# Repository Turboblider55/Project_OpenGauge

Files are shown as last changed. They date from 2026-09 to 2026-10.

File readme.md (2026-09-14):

<div align="center">

# 🛰️ OpenGauge

### Modular Vehicle Telemetry and Infotainment Companion via OBD-II

*A split dual-node wireless dashboard system for real-time vehicle diagnostics.*







[]()

</div>

---

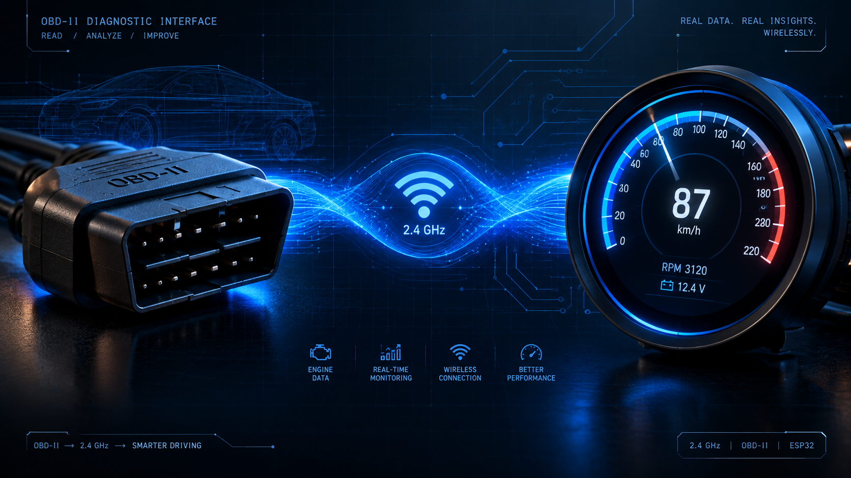
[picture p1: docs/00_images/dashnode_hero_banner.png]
OpenGauge Hero Banner

*<p align="center">OpenGauge — bridging your vehicle's CAN bus to a dashboard-mounted circular telemetry display.</p>*

---

## 📖 Overview

**OpenGauge** is a final-year IT engineering capstone project that decouples vehicle diagnostic acquisition from in-cabin display, connecting the two over a low-latency wireless link. Instead of a single bulky OBD-II dongle with an integrated screen, OpenGauge splits the system into two purpose-built nodes:

- A **discreet acquisition dongle** that lives under the steering column, silently polling the vehicle's CAN bus.
- A **dashboard/vent-mounted display puck** with a crisp circular LCD, delivering smooth animated gauges without any wired connection to the OBD port.

The result is a modular, extensible, and automotive-grade telemetry platform suitable for gauge clusters, data logging, and future infotainment integration.

---

## 🖼️ Visual Reference

| System Architecture | Circular Gauge UI |
|:---:|:---:|
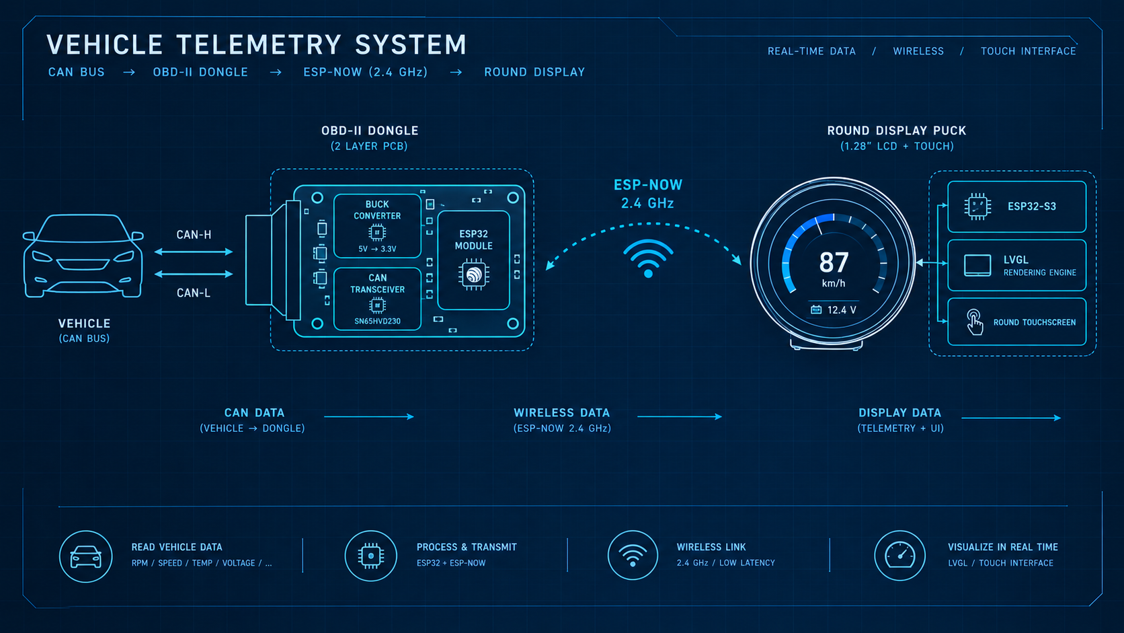
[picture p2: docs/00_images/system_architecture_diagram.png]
System Hardware Architecture Diagram
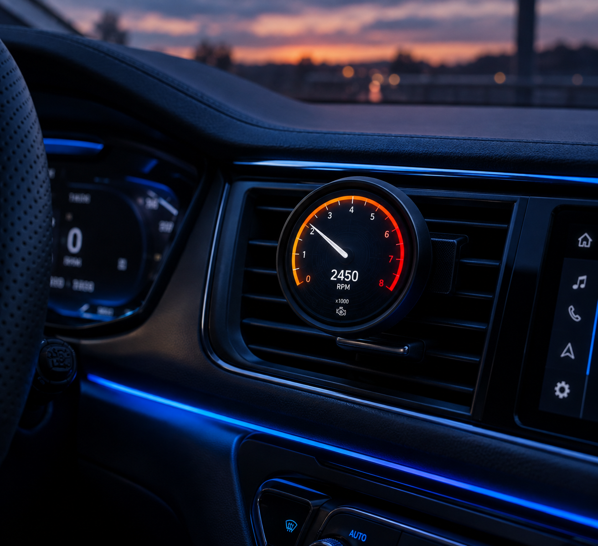
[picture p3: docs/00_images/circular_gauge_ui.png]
Circular Gauge LVGL UI Mockup
|  |  |

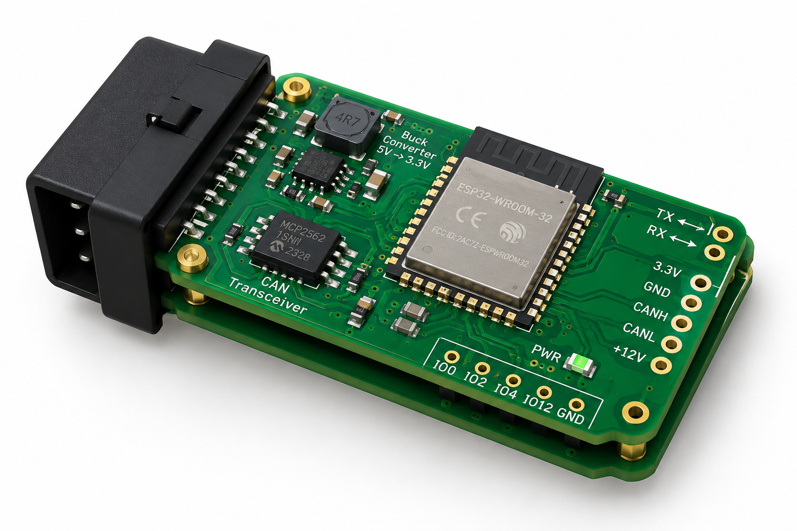
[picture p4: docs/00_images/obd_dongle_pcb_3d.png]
OBD Dongle KiCad 3D PCB Render

*<p align="center">Node 1 — OBD Acquisition Dongle, 2-layer PCB, KiCad 8 3D render.</p>*

---

## ✨ Key Features

### 🔌 Hardware / Electrical
- **Custom 2-layer PCB** for Node 1, sized to fit discreetly behind the J1962 OBD-II port.
- **Automotive-grade buck regulator** (TPS54302 / MP2315) stepping 12V (nominal vehicle rail, 9–16V transient tolerant) down to a clean 3.3V rail.
- **Dedicated CAN physical layer transceiver** (SN65HVD230) interfacing directly with the vehicle's high-speed CAN bus (CAN-H / CAN-L).
- **Input protection stage**: TVS diode transient suppression, reverse-polarity protection diode, and PTC resettable fuse on the 12V input rail.
- **ESP32-C3 module** (castellated-pad, SMD-mountable) as the acquisition MCU — compact footprint, native CAN-capable pin muxing, integrated Wi-Fi/BLE radio for ESP-NOW.
- **USB-C powered Display Node** with an **ESP32-S3** (dual-core Xtensa LX7, 8MB PSRAM) for graphics-heavy LVGL rendering.
- **Waveshare 1.28" Round Touch LCD** — GC9A01 driver (240×240, 4-wire SPI + DMA) with CST816S capacitive touch controller over I2C.

### 📡 Firmware / Protocols
- **ISO 15765-4 (CAN 11-bit, 500 kbps)** OBD-II Mode 01 PID polling: Engine RPM (`0x0C`), Vehicle Speed (`0x0D`), Coolant Temp (`0x05`), Intake Air Temp (`0x0F`).
- **ESP-NOW connectionless peer-to-peer link** — sub-5ms telemetry frame delivery, no router/AP dependency, MAC-address-paired nodes.
- **Custom lightweight binary telemetry packet schema** for minimal air-time and CPU overhead.
- **Watchdog-protected acquisition loop** with automatic PID re-query and CAN bus-off recovery handling.
- **Stretch Goal (Tier 3): BLE AVRCP metadata sniffing** — pairs with a smartphone as an AVRCP-capable BLE peripheral to extract and display the current Spotify track title / artist string on the display node.

### 🎨 Graphics / UI
- **LVGL v8/v9**-driven circular gauge cluster with animated needle sweep, smooth value interpolation, and low-latency screen redraw via DMA-backed SPI transfers.
- **Multi-page swipe UI** (touch-driven) cycling between RPM gauge, speed/temp composite view, and (stretch goal) media metadata card.
- **Configurable gauge redlines and color zones** (e.g., RPM redline warning arc) computed from live telemetry.
- **Boot splash and connection-status iconography** for wireless link health at a glance.

---

## 🧭 System Architecture

```
┌────────────────────────┐
│      VEHICLE ECU       │
│   (CAN-H / CAN-L Bus)  │
└──────────┬─────────────┘
           │  ISO 15765-4 (500 kbps)
           ▼
┌────────────────────────────────────────────┐
│           NODE 1 — OBD ACQUISITION DONGLE  │
│  ┌────────────┐     ┌────────────────┐     │
│  │ J1962 Port │ --> │ SN65HVD230 CAN │     │
│  │  (12V/GND) │     │  Transceiver   │     │
│  └─────┬──────┘     └───────┬────────┘     │
│        │                    │              │
│        ▼                    ▼              │
│  ┌────────────┐     ┌────────────────┐     │
│  │ Buck Reg.  │     │  ESP32-C3      │     │
│  │ 12V→3.3V   │ --> │  (CAN parse +  │     │
│  │(TPS54302)  │     │   PID polling) │     │
│  └────────────┘     └───────┬────────┘     │
└─────────────────────────────┼──────────────┘
                              │
                              │  ESP-NOW (2.4GHz, <5ms)
                              ▼
┌─────────────────────────────────────────────────────┐
│           NODE 2 — DISPLAY NODE                     │
│  ┌───────────────┐     ┌────────────────────┐       │
│  │  ESP32-S3     │ --> │  LVGL v8/v9 Engine │       │
│  │ (Dual-Core,   │     │  (Gauge Rendering) │       │
│  │  8MB PSRAM)   │     └─────────┬──────────┘       │
│  └───────┬───────┘               │                  │
│          │  4-wire SPI + DMA     ▼                  │
│          ▼                 ┌───────────────────┐    │
│  ┌─────────────────┐       │ GC9A01 240x240    │    │
│  │  CST816S Touch  │ <---> │ Round LCD Panel   │    │
│  │  (I2C)          │       └───────────────────┘    │
│  └─────────────────┘                                │
│          USB-C Powered (Dash/Vent Mounted)          │
└─────────────────────────────────────────────────────┘
```

---

## 📁 Repository Structure

```
opengauge/
├── hardware/
│   ├── obd_node_pcb/
│   │   ├── kicad_project/          # .kicad_pro, .kicad_sch, .kicad_pcb
│   │   ├── gerbers/                # Fabrication-ready Gerber + drill files
│   │   ├── bom/                    # Bill of Materials (CSV/XLSX)
│   │   └── 3d_renders/             # STEP/PNG exports
│   └── shared_symbols_footprints/  # Custom KiCad libraries
│
├── firmware/
│   ├── obd_node/                   # ESP32-C3 acquisition firmware
│   │   ├── src/
│   │   │   ├── can_driver.c
│   │   │   ├── obd_pid_parser.c
│   │   │   ├── espnow_tx.c
│   │   │   └── main.c
│   │   ├── include/
│   │   └── platformio.ini
│   │
│   └── display_node/               # ESP32-S3 display firmware
│       ├── src/
│       │   ├── lvgl_conf/
│       │   ├── ui/
│       │   │   ├── gauge_rpm.c
│       │   │   ├── gauge_speed_temp.c
│       │   │   └── media_card.c
│       │   ├── espnow_rx.c
│       │   ├── touch_driver.c
│       │   └── main.c
│       ├── include/
│       └── platformio.ini
│
├── mechanical/
│   ├── dongle_enclosure/           # STL + STEP files, J1962 shroud
│   └── display_puck_mount/         # STL + STEP files, vent/dash clip
│
├── docs/
│   ├── images/                     # README visual assets
│   ├── wiring_diagrams/
│   ├── datasheets/
│   └── project_report.pdf
│
├── LICENSE
└── README.md
```

---

## 🔧 Pin Mapping

### Node 1 — ESP32-C3 (OBD Acquisition Dongle)

| ESP32-C3 Pin | Function | Connected To |
|:---:|:---|:---|
| GPIO4 | `CAN_TX` (TWAI TX) | SN65HVD230 `TXD` |
| GPIO5 | `CAN_RX` (TWAI RX) | SN65HVD230 `RXD` |
| GPIO2 | Status LED — Power | Green LED (via 330Ω resistor)|
| GPIO3 | Status LED — Link | Blue LED (via 330Ω resistor) |
| GPIO8 | Status LED — Fault | Red LED (via 330Ω resistor)  |
| 3V3 | Regulated Supply | TPS54302 `VOUT` |
| GND | Common Ground | Vehicle Chassis / J1962 Pin 4|

### Node 2 — ESP32-S3 (Display Node → Waveshare 1.28" GC9A01/CST816S)

| ESP32-S3 Pin | Function | Display Module Pin |
|:---:|:---|:---|
| GPIO11 | SPI `MOSI` | `SDA` (Display Data) |
| GPIO12 | SPI `SCLK` | `SCL` (Display Clock) |
| GPIO10 | SPI `CS` | `CS` |
| GPIO9 | `DC` (Data/Cmd) | `DC` |
| GPIO14 | `RST` | `RES` |
| GPIO13 | Backlight PWM | `BL` |
| GPIO7 | I2C `SDA` (Touch) | `TP_SDA` (CST816S) |
| GPIO6 | I2C `SCL` (Touch) | `TP_SCL` (CST816S) |
| GPIO15 | Touch `INT` | `TP_INT` |

> ⚠️ Pin assignments are configurable via `sdkconfig` / `platformio.ini` build flags — table reflects default reference firmware wiring.

---

## 🗓️ Development Roadmap (8-Week Capstone Sprint)

| Week | Milestone | Focus Area |
|:----:|:---|:---|
| **1** | Proof-of-Concept | Breadboard ESP32-C3 + MCP2515/SN65HVD230, validate CAN sniffing against a bench ECU simulator or real vehicle OBD port. |
| **2** | OBD Protocol Layer | Implement ISO 15765-4 Mode 01 PID request/response parsing (RPM, Speed, Coolant Temp, Intake Temp). |
| **3** | Wireless Link | Establish ESP-NOW pairing between ESP32-C3 and ESP32-S3; benchmark round-trip latency (<5ms target). |
| **4** | Hardware Fabrication | Finalize KiCad schematic + layout for Node 1 dongle PCB; submit Gerbers for fab; order SMD components. |
| **5** | Display Bring-Up | Bring up Waveshare 1.28" GC9A01 over SPI/DMA; integrate LVGL v8/v9; validate CST816S touch input. |
| **6** | UI/UX Integration | Build animated circular gauge cluster, multi-page swipe navigation, live telemetry binding via ESP-NOW RX. |
| **7** | Enclosure + Stretch Goal | 3D-print/CAD dongle + display puck enclosures; attempt BLE AVRCP Spotify metadata stretch goal. |
| **8** | Final Integration & Defense | End-to-end vehicle testing, documentation finalization, capstone defense presentation & demo. |

---

## 🛠️ Getting Started

### Prerequisites
- [PlatformIO](https://platformio.org/) or ESP-IDF v5.x toolchain
- [KiCad 8](https://www.kicad.org/) for hardware design files
- A vehicle (or CAN bus simulator) with an accessible J1962 OBD-II port
- Basic SMD soldering/rework capability for dongle assembly

### Flashing the Firmware
```bash
# Clone the repository
git clone https://github.com/<your-username>/opengauge.git
cd opengauge

# Flash the OBD Acquisition Node (ESP32-C3)
cd firmware/obd_node
pio run --target upload

# Flash the Display Node (ESP32-S3)
cd ../display_node
pio run --target upload
```

---

## 📜 License & Disclaimer

This project is released under the **MIT License** — see [`LICENSE`](LICENSE) for full terms.

> ⚠️ **Automotive Safety Disclaimer**
> OpenGauge is designed strictly as a **passive, read-only telemetry monitoring device**. It queries standard OBD-II Mode 01 PIDs and does **not** transmit, inject, or alter any CAN bus frames, ECU parameters, or vehicle control systems. This project is intended for educational and diagnostic-display purposes only and is **not** a certified automotive safety, emissions, or control device. Use of this hardware is entirely at the user's own risk; the authors assume no liability for vehicle malfunction, electrical damage, or safety incidents arising from installation or use. Always ensure proper fusing, isolation, and OBD-II port compliance before connecting any custom hardware to a vehicle's diagnostic bus.

---

<div align="center">

**OpenGauge** — Built with ❤️ as a final-year IT Engineering Capstone Project.

</div>

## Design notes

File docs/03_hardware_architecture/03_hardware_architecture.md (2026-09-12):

# 🚗⚡ 03 — Hardware Architecture

> 🔧 **Open Gauge** is a two-board, wireless-linked telemetry system: an **OBD-II Acquisition
> Dongle** 📡 (Board 1, ESP32-C3) that reads the vehicle's CAN bus, and a **Cockpit
> Display Node** 🖥️ (Board 2, ESP32-S3) that renders the data on a round touch
> display. The boards talk to each other over ESP-NOW 📶 — no Wi-Fi router, no
> pairing ceremony, **< 5 ms** typical latency.

📘 This document is a quick-start hardware reference for contributors. For full
derivations, component-selection math, and manufacturing detail, see the
formal hardware specification chapter in `/docs/thesis/`.

---

## 🗺️ 1. High-Level System Architecture

```
                          VEHICLE (12V / 9-16V rail, CAN bus)
 ┌───────────────────────────────────────────────────────────────────────┐
 │  J1962 OBD-II Port                                                    │
 │   Pin16 (12V) Pin4/5 (GND) Pin6 (CAN_H) Pin14 (CAN_L)                 │
 └──────────────┬───────────────────────────┬────────────────────────────┘
                │                            │
                ▼                            ▼
     ┌───────────────────────┐        ┌──────────────────────┐
     │   BOARD 1: OBD        │        │  CAN transceiver     │
     │   ACQUISITION         │◄──────►│  SN65HVD230          │
     │   DONGLE              │        └──────────────────────┘
     │  (ESP32-C3-WROOM-02)  │
     │  - TWAI/CAN polling   │
     │  - Buck 12V→3.3V      │
     │  - Reverse/OV protect │
     └──────────┬────────────┘
                │  ESP-NOW (2.4 GHz, connectionless, ~10 byte packet)
                │  < 5 ms latency, < 3 ms TX time
                ▼
     ┌─────────────────────────┐
     │   BOARD 2: DISPLAY      │
     │   NODE                  │
     │  (ESP32-S3-WROOM-1)     │
     │  - Core0: ESP-NOW/BLE   │
     │  - Core1: LVGL/DMA      │
     │  - GC9A01 round TFT     │
     │  - CST816S touch        │
     │  - USB-C / LiPo power   │
     └───────────┬─────────────┘
                 │
                 ▼
        1.28" round cockpit gauge
        (mounted on vent / bezel)
```

💡 **Design rationale in one line:** splitting acquisition from display lets the
dongle stay small, cheap, and disposable in a harsh electrical environment,
while the display node is optimized purely for graphics and battery-backed
portability — neither board carries silicon it doesn't need.

---

## 🔌 2. Board 1 — OBD-II Acquisition Dongle

### 📐 2.1 Block Diagram

```
 12V IN ──► Reverse-Polarity ──► TVS Clamp ──► TPS54302 ──► 3.3V RAIL
 (Pin16)     (SS34 Schottky)     (SMAJ24A)      Buck Conv.        │
                                                                  ├──► ESP32-C3-WROOM-02
                                                                  └──► SN65HVD230 (CAN PHY)
 CAN_H/L ──► NUP2105L ESD ──► SN65HVD230 ──► GPIO4 (RX) / GPIO5 (TX)
 (Pin6/14)     array            transceiver      of ESP32-C3

 USB-C ──► 5.1k CC pulldowns ──► BAT54 Schottky (back-feed block) ──► GPIO18/19
                                                                       (native USB D-/D+)
```

### 🔋 2.2 Power Step-Down

| ⚙️ Parameter | 📊 Value |
|---|---|
| Topology | Synchronous buck (integrated FET) |
| IC | TI TPS54302 (alt. MPS MP2315) |
| Input range | 4.5 V – 28 V (covers 6 V cold-crank to 40 V load-dump, clamped) |
| Output | 3.3 V @ up to 1.5–2.0 A |
| Switching freq. | 400–500 kHz |
| Inductor | 4.7–10 µH shielded, Isat ≥ 2.0 A |
| Input caps | 10 µF 50 V X7R + 100 nF HF bypass |
| Output caps | 2× 22 µF 10 V X7R |

### 🛰️ 2.3 CAN Bus Transceiver

| ⚙️ Parameter | 📊 Value |
|---|---|
| IC | TI SN65HVD230DR (alt. NXP TJA1051T/3) |
| Standard | ISO 11898-2 (high-speed CAN), used per ISO 15765-4 diagnostic framing |
| Bus speed | 500 kbps, 11-bit ID |
| Termination | 120 Ω footprint on 2-pin jumper JP1, **default OPEN** — vehicle bus already presents the correct ~60 Ω differential load; do not close JP1 in-vehicle |
| ESD protection | NUP2105L (or PESD1CAN) dual-line automotive TVS array on CAN_H/CAN_L |

### 🛡️ 2.4 Safety Isolation

- **Reverse polarity:** SS34 Schottky (40 V, 3 A) in series with the 12 V input pin — blocks reverse-wired power without the drop penalty of a silicon diode bridge.
- **Load dump / OV clamp:** SMAJ24A (or SMBJ28A) unidirectional TVS across 12 V and GND, sized to survive ISO 7637-2 pulse 5 transients.
- **Dual-power conflict:** a BAT54/SS14 Schottky on the USB-C 5 V VBUS rail stops the vehicle-derived 3.3 V/12 V domain from back-feeding a laptop's USB port during bench calibration with the dongle simultaneously plugged into both.

### 🧷 2.5 Board 1 Pinout & Net Map

| ESP32-C3 Pin | Net | Function |
|---|---|---|
| GPIO18 | USB_D- | Native USB Serial/JTAG (flashing) |
| GPIO19 | USB_D+ | Native USB Serial/JTAG (flashing) |
| GPIO04 | CAN_RX | From SN65HVD230 RXD |
| GPIO05 | CAN_TX | To SN65HVD230 TXD |
| GPIO09 | BOOT_SEL | Strapping pin, 10k pullup + tactile switch to GND |
| EN | RESET | 10k pullup + 1 µF to GND |
| GPIO08 | STATUS_LED | Active-low indicator |
| Pin16 (J1962) | VBAT_12V | Vehicle battery feed → reverse-protect → buck |
| Pin6 (J1962) | CAN_H | To transceiver |
| Pin14 (J1962) | CAN_L | To transceiver |
| Pin4/5 (J1962) | GND | Chassis / signal ground |

---

## 🖥️ 3. Board 2 — Cockpit Display Node

### 📐 3.1 Block Diagram

```
 USB-C 5V ──► PTC Fuse ──► SMAJ5.0A ──► TP4056 Charger ──► LiPo Cell (3.7V)
   │            (0805)       clamp           │                   │
   │                                         │                   │
   │  USBLC6-2SC6 ESD array on D+/D-         ▼                   ▼
   │                                  Gate of AO3401A P-FET ◄── 100k pulldown
   ▼                                         │
 ESP32-S3 native USB (GPIO19/20)             ▼
                                   SS14 Schottky ──► SYS_RAIL ──► ME6211C33 LDO ──► 3.3V
                                                                                       │
                                                                            ┌──────────┴──────────┐
                                                                            ▼                      ▼
                                                                   ESP32-S3-WROOM-1        GC9A01 TFT + CST816S
                                                                   (dual-core, 8MB PSRAM)   (SPI + I2C)
```

### 🧠 3.2 Processing Core

- **Module:** ESP32-S3-WROOM-1-N8R8 — dual-core Xtensa LX7 @ 240 MHz, 512 kB SRAM, 8 MB Octal PSRAM, 8 MB Quad SPI flash.
- **Core allocation:** Core 0 runs the ESP-NOW receive/unpack path and background BLE; Core 1 owns the LVGL render loop and DMA-driven SPI transfers to the panel, keeping graphics jitter-free regardless of radio traffic.

### 🎛️ 3.3 Display & Touch Wiring (SPI/I2C)

| Signal | ESP32-S3 GPIO | Bus |
|---|---|---|
| LCD_MOSI | GPIO11 | SPI |
| LCD_SCLK | GPIO12 | SPI |
| LCD_CS | GPIO10 | SPI |
| LCD_DC | GPIO09 | SPI (data/command) |
| LCD_RST | GPIO14 | GPIO |
| LCD_BL | GPIO13 | PWM backlight |
| TOUCH_SDA | GPIO01 | I2C |
| TOUCH_SCL | GPIO02 | I2C |
| TOUCH_INT | GPIO03 | GPIO (interrupt) |
| TOUCH_RST | GPIO04 | GPIO |

Panel: Waveshare 1.28" round IPS TFT, GC9A01 driver, 240×240 RGB565, 4-wire SPI with DMA. Touch: CST816S capacitive controller over I2C.

### 🔌🛡️ 3.4 USB Protection

1. **0805 PTC resettable fuse** — 500 mA hold / 1 A trip, first line of over-current defense.
2. **SMAJ5.0A TVS** — clamps VBUS transients above ~5.5 V.
3. **USBLC6-2SC6** — low-capacitance ESD array on D+/D- to protect the native USB PHY.

### 🔀 3.5 Power-Path Topology (P-MOSFET Auto-Switchover)

The board never runs both sources into the rail simultaneously; instead the
P-channel MOSFET (AO3401A) acts as an ideal-diode-like switch controlled by
VBUS presence:

- 🔌 **USB present:** VBUS pulls the P-FET gate HIGH → FET **off** → system load draws from USB through the SS14 Schottky, while TP4056 charges the LiPo in parallel.
- 🔋 **USB absent:** 100 kΩ pulldown drags the gate to GND → P-FET **on** (< 30 mV drop) → system draws directly from the battery.

Downstream, the ME6211C33M5G LDO (SOT-23-5, 500 mA, ~100 mV dropout) holds a clean 3.3 V rail down to a cell voltage of roughly 3.4 V, covering the LiPo discharge curve down to near-empty.

### 🧷 3.6 Board 2 Pinout & Net Map

| ESP32-S3 Pin | Net | Function |
|---|---|---|
| GPIO19 | USB_D- | Native USB |
| GPIO20 | USB_D+ | Native USB |
| GPIO11 | LCD_MOSI | Display SPI |
| GPIO12 | LCD_SCLK | Display SPI |
| GPIO10 | LCD_CS | Display SPI |
| GPIO09 | LCD_DC | Display SPI |
| GPIO14 | LCD_RST | Display reset |
| GPIO13 | LCD_BL | Backlight PWM |
| GPIO01 | TOUCH_SDA | Touch I2C |
| GPIO02 | TOUCH_SCL | Touch I2C |
| GPIO03 | TOUCH_INT | Touch interrupt |
| GPIO04 | TOUCH_RST | Touch reset |
| GPIO08 | BATT_ADC | Battery sense via 100k/100k divider |

---

## ⚠️ 4. Critical PCB Layout Rules

1. 🔥 **Hot-loop containment (Board 1 buck, Board 2 charger/LDO):** keep the switch node, input cap, and inductor loop as small and tight as physically possible; route the input capacitor's return path directly under the IC's GND pin, not around the board edge. A large hot loop is the single biggest source of radiated EMI on both boards.
2. 🛰️ **Differential CAN routing:** route CAN_H/CAN_L as a tightly coupled differential pair, matched length (±5 mil target), constant spacing, away from the buck converter's switch node and any clock lines. Keep the pair over an unbroken ground reference plane — no plane splits underneath.
3. 📶 **2.4 GHz antenna keepout:** maintain the module vendor's specified copper keepout (typically no copper, silkscreen, or ground pour on any layer directly under or adjacent to the WROOM antenna edge) on both the ESP32-C3 and ESP32-S3 modules, and orient each antenna away from large metal fill and connectors where possible.
4. 🌐 **Star grounding at the power entry:** on Board 1, bring chassis GND and signal GND together at a single point near the J1962 connector rather than merging them arbitrarily across the board, to keep CAN common-mode noise out of the MCU's digital ground.
5. 🔋 **Battery/charge path (Board 2):** keep TP4056 thermal pad and its sense resistor traces short and away from the LDO's heat path; the P-FET body diode orientation must be verified against the schematic before layout — a reversed footprint silently defeats the power-path protection.

---

📎 *For component-level derivations (inductor ripple-current sizing, feedback divider equations, SPI timing/FPS budget, and the full Bill of Materials), see the companion formal hardware specification chapter.*

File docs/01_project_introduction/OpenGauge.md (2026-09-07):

# 🚗 Project Charter & Scope Document: DashNode

**Project Name:** OpenGauge (Modular Vehicle Telemetry and Infotainment Companion via OBD-II)  
**Author:** IT Engineering Candidate  
**Project Type:** Undergraduate Capstone / Final-Year Engineering Project  
**Target Completion:** End of Semester (approx. 6–8 weeks)  
**Status:** 🟡 In Progress  

---

## 📌 1. Executive Summary & Background

Modern passenger vehicles generate substantial telemetry across internal controller area networks (CAN buses), accessible via the mandatory On-Board Diagnostics (OBD-II / J1962) port. However, factory instrument clusters often omit critical real-time performance indicators—such as exact coolant temperatures, oil temperatures, intake manifold pressure, or dynamic bus load. Aftermarket solutions typically fall into two categories: bulky, proprietary gauges that clutter the dashboard with messy power and signal wiring, or generic smartphone apps that require slow manual Bluetooth pairing and drain mobile device batteries.

**OpenGauge** is a modular, split-architecture automotive telemetry platform. It decouples data acquisition from visualization:
* 🔌 An ultra-compact **Dongle Node** plugs directly into the vehicle's OBD-II port, harvesting vehicle power and reading raw high-speed CAN frames.
* 🖥️ A dedicated, dashboard-mounted **Display Node** receives pre-processed telemetry wirelessly, rendering smooth, driver-oriented graphical instruments in real time.

By utilizing dedicated hardware transceivers and a direct peer-to-peer wireless link, DashNode provides a zero-latency, cable-free secondary display that powers on automatically with the vehicle.

---

## 🎯 2. Project Goals & Success Criteria

### 2.1 Primary Engineering Goals
* **[G-1]** 🛠️ Design and fabricate a custom, dual-layer Printed Circuit Board (PCB) integrating an automotive-grade DC-DC buck converter and a dedicated 3.3V CAN physical layer transceiver.
* **[G-2]** ⚡ Implement an embedded firmware pipeline that polls and parses standard ISO 15765-4 (CAN 11-bit/500kbps) OBD-II Parameter IDs (PIDs) with minimal bus latency.
* **[G-3]** 📡 Establish a robust, low-latency, connectionless peer-to-peer wireless telemetry link between the acquisition node and the display node.
* **[G-4]** 📊 Develop a responsive graphical user interface (GUI) on a round/compact TFT display capable of rendering gauge animations at ≥ 30 FPS without blocking communication routines.

### 2.2 Success Metrics
* 🔋 **Power Stability:** On-board buck converter operates reliably with input voltages from $9.0\,\text{V}$ to $16.0\,\text{V}$ DC without thermal throttling or shutdown.
* 🛡️ **Bus Integrity:** Passive read/poll loop introduces zero error frames onto the vehicle's high-speed CAN network.
* ⏱️ **Refresh Rate:** High-priority parameters (Engine RPM, Vehicle Speed) update on screen at $\ge 10\,\text{Hz}$ (latency $\le 100\,\text{ms}$).
* 🚀 **Cold Boot Time:** Display node boots and renders initial telemetry within **a few second** of vehicle ignition switch-on.

---

## 🔍 3. Project Scope & Boundary Definition

### 3.1 In-Scope (Committed Deliverables)
* 📐 **Custom Dongle Hardware:** Schematic capture, component selection, PCB layout, assembly, and testing of the OBD-II acquisition board.
* 🔌 **Power Supply Circuitry:** On-board step-down regulation with reverse-polarity protection, input filtering, and transient voltage suppression (TVS).
* 💻 **Firmware - Acquisition Node:** Initialization of the CAN/TWAI peripheral, cyclic scheduling of standard OBD-II PID requests (Mode 01), message parsing, and wireless packet broadcast.
* 🎨 **Firmware - Display Node:** Wireless packet reception, data validation, and GUI rendering using the LVGL graphics library on a SPI-driven TFT screen.
* 🖨️ **Mechanical CAD:** 3D-printable protective enclosure for the OBD-II dongle conforming to standard J1962 connector envelopes.

### 3.2 Out-of-Scope (Explicitly Excluded)
* ❌ **Writing / Clearing Diagnostic Trouble Codes (DTCs):** To avoid accidental clearing of emissions readiness monitors, the system will operate exclusively as a read-only telemetry display.
* ❌ **Proprietary Manufacturer CAN Reverse-Engineering:** Non-standard manufacturer PIDs (e.g., proprietary BMW, VAG, or Ford factory bus packets) are excluded; the scope is strictly restricted to legislated OBD-II PIDs.
* ❌ **Full-Resolution Video Streaming / Screen Mirroring:** No Android Auto or Apple CarPlay video stream mirroring. The display hardware is optimized for vector UI rendering, not video decoding.
* ❌ **Vehicle Control Intervention:** The system will never transmit actuation frames (accelerator, steering, brake, or body control overrides).

---

## 🚦 4. MVP Constraints & Tiered Feature Breakdown

```
┌───────────────────────────────────────────────────────────┐
│              TIER 1: Minimum Viable Product (MVP)         │
│  • Custom OBD PCB (Buck + CAN + MCU footprint)            │
│  • Vehicle CAN polling: RPM, Speed, Coolant Temperature   │
│  • Peer-to-peer wireless telemetry stream                 │
│  • Basic digital dial & numerical gauge UI on screen      │
└─────────────────────────────┬─────────────────────────────┘
                              │ (If on schedule)
                              ▼
┌───────────────────────────────────────────────────────────┐
│                 TIER 2: Core Engineering Polish           │
│  • Low-power sleep mode during engine-off state           │
│  • Secondary screens: Min/Max trip telemetry, Intake Temp │
│  • 3D-printed clip/case for air-vent mounting             │
└─────────────────────────────┬─────────────────────────────┘
                              │ (Strictly optional)
                              ▼
┌───────────────────────────────────────────────────────────┐
│                 TIER 3: Extended / Stretch Goals          │
│  • Bluetooth AVRCP (Spotify Track / Artist text display)  │
│  • Turn-by-Turn navigation arrow icon notification parsed │
│    from companion mobile app / BLE notification service   │
└───────────────────────────────────────────────────────────┘
```

### Critical MVP Technical Constraints
* ⚡ **Safety Isolation:** Solder jumper must allow disabling the $120\,\Omega$ bus termination resistor to prevent over-terminating an active vehicle CAN bus.
* 📏 **Board Dimensions:** OBD dongle PCB footprint must not exceed $55\,\text{mm} \times 35\,\text{mm}$ to prevent interference with driver footwell controls.
* 📦 **Component Availability:** All silicon (switching ICs, transceivers, passives) must be selected from in-stock parts at standard rapid-assembly vendors (e.g., JLCPCB SMT library / LCSC).

---

## 📦 5. Project Deliverables

| Deliverable ID | Category | Description | Format / Artifact |
| :--- | :--- | :--- | :--- |
| **DEL-01** | 📄 Documentation | Complete System Architecture & Functional Specification | Markdown / PDF in `/docs` |
| **DEL-02** | 🖥️ Hardware | KiCad Schematic, PCB Layout, Gerber & Drill files | `.kicad_sch`, `.kicad_pcb`, zip in `/hardware` |
| **DEL-03** | 📋 Hardware | Bill of Materials (BOM) with vendor LCSC/DigiKey part numbers | `bom.csv` |
| **DEL-04** | 💻 Firmware | Acquisition Node firmware (CAN parsing + Wireless TX) | C++ source code in `/firmware/obd_node` |
| **DEL-05** | 🎨 Firmware | Display Node firmware (LVGL UI + Wireless RX) | C++ source code in `/firmware/display_node` |
| **DEL-06** | 🖨️ Mechanical | Enclosure CAD models for 3D printing | `.step` / `.stl` in `/mechanical` |
| **DEL-07** | 🎓 Academic | Final Thesis Paper & Demonstration Video | Final University Report (PDF) |

---

## ⚠️ 6. Risk Management & Contingency Matrix

| Identified Risk | Severity | Likelihood | Mitigation Strategy |
| :--- | :--- | :--- | :--- |
| **PCB Layout/Fab Error** (e.g., buck converter failure) | 🔴 High | 🟡 Medium | Order bare breakouts of key ICs in parallel; reserve space for manual bodge-wires; follow reference layouts strictly. |
| **Vehicle Incompatibility** (ECU timeout or silent bus) | 🔴 High | 🟢 Low | Develop on a bench setup using an inexpensive USB-to-CAN analyzer or a secondary MCU programmed as an OBD-II simulator. |
| **Display Framerate Lag** (SPI bus blocking execution) | 🟡 Medium | 🟡 Medium | Use ESP32 dual-core task affinity: Core 0 dedicated to wireless communication, Core 1 running LVGL graphics with DMA-driven SPI. |
| **Bluetooth Phone Stack Complexity** (Timeline threat) | 🟡 Medium | 🔴 High | Lock BLE/Spotify/Maps features strictly to Tier 3. If MVP is running behind schedule by Week 5, drop BLE phone integration entirely without risking project pass criteria. |

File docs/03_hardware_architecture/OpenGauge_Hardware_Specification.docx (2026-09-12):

Hardware Engineering Chapter

Open Gauge: An Open-Source, Dual-Node Wireless Vehicle Telemetry and Secondary Instrument Gauge Platform

This chapter presents the complete hardware engineering specification for Open Gauge, covering system-level design rationale, the OBD-II acquisition dongle (Board 1), the cockpit display node (Board 2), the consolidated bill of materials, and the manufacturing and PCB layout guidelines used to realize the design.

# 1. System-Level Design Rationale

## 1.1 Asymmetric Dual-Node Topology

Open Gauge partitions functionality across two physically separate, wirelessly linked printed circuit boards rather than adopting the conventional single-board approach used by most hobbyist OBD-II gauge projects. Board 1 (the Acquisition Dongle) resides permanently inside the OBD-II tunnel, exposed to the harshest electrical environment in the vehicle, while Board 2 (the Display Node) is a battery-backed, purely-digital cockpit instrument mounted for driver visibility. This asymmetry is a deliberate engineering decision, not an artifact of convenience, and is justified along four axes below.

### 1.1.1 Electrical isolation of the hostile domain

A traditional single-board wired gauge cluster must route both the raw vehicle power/CAN domain and the low-noise display/touch domain on one substrate, forcing the sensitive SPI and I2C traces feeding the display controller to share a ground plane with a switching buck converter fed directly from an unregulated automotive rail. By splitting the boards, all automotive-grade transient handling (load dump, reverse polarity, ESD on the CAN lines) is physically confined to Board 1, and the only signal crossing the boundary to Board 2 is a 2.4 GHz radio packet — there is no galvanic connection between the vehicle electrical system and the cockpit-mounted display at all.

### 1.1.2 Independent power budgets and duty cycles

Board 1 is permanently powered whenever the vehicle battery is connected (or gated by switched 12 V, depending on installation), and its power budget is dominated by the CAN transceiver and RF broadcast duty cycle. Board 2 is a battery-powered, user-facing instrument that must survive extended operation off a small LiPo cell when removed from USB power, and its budget is dominated by the TFT backlight and the LVGL render pipeline. Decoupling the two boards allows each power subsystem to be optimized independently: Board 1 needs a wide-input automotive buck regulator, while Board 2 needs an efficient linear power-path with instant source switchover rather than a second automotive-rated buck stage it would never use in normal operation.

### 1.1.3 Mechanical placement freedom

The OBD-II port is fixed by the vehicle manufacturer under the steering column, an ergonomically poor location for a driver-facing gauge. A single-board design would force an unsightly cable run from the port to the dash. The dual-node topology lets Board 1 remain hidden at the port while Board 2 is placed anywhere convenient — vent-mounted, bezel-mounted, or handheld — with ESP-NOW eliminating the wiring harness entirely.

### 1.1.4 Fault containment and field serviceability

Because the boards are only coupled over RF, a fault on one node (e.g. a CAN transceiver damaged by an out-of-spec transient) cannot propagate to or brick the other. Each board can be reflashed, replaced, or bench-tested independently over its native USB interface without disturbing the other node, which materially reduces field-service complexity relative to a monolithic board where a single fault domain covers both acquisition and display electronics.

## 1.2 Automotive Power Rail Dynamics

Board 1 draws power directly from the vehicle’s 12 V nominal rail at the OBD-II connector, a supply that is nominal in name only. The regulator, input protection network, and PCB layout were all sized against the transient environment defined by ISO 7637-2 and observed alternator/starter behavior, summarized below.

Transient class | Origin | Typical magnitude
Pulse 1 | Supply line disconnect while inductive loads are switched | −100 V (clamped), fast decay
Pulse 2a | Supply interruption due to voltage drop at wiring resistance | +75 V transient, short duration
Pulse 3a/3b | Transients from switching processes on the bus wiring | ±150 V, sub-microsecond, fast repetitive
Pulse 5b (load dump) | Alternator field-decay after battery disconnect under charge | +40 V typical, several hundred ms, up to seconds
Cold crank | Starter motor draw collapsing battery voltage | Down to 6 V for ~15–20 ms, ringing recovery
Alternator ripple | Rectifier ripple superimposed on the charging rail | ±0.5–1 V at 3× to 6× engine RPM harmonic

Table 1.1 — ISO 7637-2 conducted transient classes relevant to the Board 1 input stage.

The design response to this environment is layered rather than relying on a single component: the TPS54302 buck regulator is specified for a 4.5–28 V continuous input range, comfortably spanning cold-crank sag (6 V) through nominal charging voltage (13.8–14.4 V); a SMAJ24A/SMBJ28A unidirectional TVS diode clamps load-dump energy at the input before it reaches the regulator’s absolute maximum rating; and the SS34 series Schottky diode blocks reverse-polarity connection at the connector, which — unlike the transient pulses above — is a static fault condition rather than a momentary event and must be tolerated indefinitely without damage. Alternator ripple, being a relatively low-amplitude, low-frequency artifact well within the buck converter’s input operating range and further attenuated by the input bulk capacitance, does not require dedicated suppression beyond the standard input filter network.

# 2. Board 1: OBD-II Telemetry Acquisition Dongle

## 2.1 Core Processing: ESP32-C3-WROOM-02

Board 1 is built around the Espressif ESP32-C3-WROOM-02-N4 castellated SMT module, integrating a 32-bit single-core RISC-V processor, 4 MB of SPI flash inside an RF shielding can, and the on-chip TWAI (Two-Wire Automotive Interface) controller that implements the CAN 2.0B protocol engine used for OBD-II polling.

The core clock is derived from a 40 MHz external crystal reference through the chip’s internal phase-locked loop, which multiplies the reference up to the processor’s 160 MHz operating frequency:

fCPU = fXTAL × NPLL = 40 MHz × 4 = 160 MHz

This single-core budget is sufficient because Board 1’s workload is I/O-bound rather than compute-bound: the dominant task is scheduling periodic CAN request frames, parsing single-frame ISO 15765-4 responses, and packing the result into a fixed 10-byte ESP-NOW payload, none of which approaches the processor’s throughput ceiling even at the fast-polling group’s 10–20 Hz cadence.

## 2.2 Power Stage Analysis — TPS54302 Synchronous Buck

The TPS54302 is a synchronous step-down converter with integrated high-side and low-side FETs, selected for its wide 4.5–28 V input range (matching the transient envelope described in §1.2), integrated compensation, and small external component count. The design targets a fixed 3.3 V output at up to 1.5–2.0 A, switching at approximately 400–500 kHz.

### 2.2.1 Output inductor selection

The output inductor is sized from the target peak-to-peak ripple current, expressed as a fraction KIND of the maximum DC load current (a design value of KIND = 0.3 – 0.4 is standard practice for this class of automotive buck converter, balancing inductor size against ripple-induced core and conduction losses):

L1 = [VOUT × (VIN(max) − VOUT)] / [VIN(max) × fSW × ΔIL]

where ΔIL = KIND × IOUT(max). Substituting a worst-case VIN(max) of 16 V (clamped alternator ceiling), VOUT = 3.3 V, fSW = 450 kHz, IOUT(max) = 1.5 A and KIND = 0.35 gives ΔIL ≈ 0.525 A and yields an inductor value in the 6.5–7.5 µH range — consistent with the specified 4.7–10 µH shielded power inductor with a saturation current rating ISAT ≥ 2.0 A, which retains adequate margin above the calculated peak current (IOUT(max) + ΔIL/2 ≈ 1.76 A).

### 2.2.2 Input capacitor ESR and RMS current

The buck converter draws pulsed current from the input rail at the switching frequency; the input capacitor must supply this ripple current locally so that only DC (and low-frequency alternator ripple, already discussed) is drawn from the harness. The input capacitor RMS current requirement is approximated by:

ICIN(RMS) ≈ IOUT × √[D × (1 − D)]

where D = VOUT/VIN is the converter duty cycle. At the nominal 13.8 V input, D ≈ 0.24, giving ICIN(RMS) ≈ 0.65 × IOUT. The specified 10 µF 50 V X7R ceramic input capacitor, combined with a 100 nF high-frequency bypass placed immediately at the IC’s VIN pin, presents ESR in the low tens of milliohms — low enough that the resulting input ripple voltage (ΔVIN ≈ ICIN(RMS) × ESR) stays a small fraction of a volt, well within the regulator’s tolerance for line noise.

### 2.2.3 Feedback divider for fixed 3.3 V output

For adjustable-output variants of this converter family, the output voltage is programmed by a resistive divider from VOUT to the feedback pin, referenced against the internal bandgap VREF (typically 0.8 V):

VOUT = VREF × (1 + R1/R2)

Rearranged for a fixed 3.3 V target with a standard R2 = 10.0 kΩ (1% tolerance) lower divider resistor:

R1 = R2 × (VOUT/VREF − 1) = 10.0 kΩ × (3.3/0.8 − 1) ≈ 31.25 kΩ

The nearest E96 1% value (31.6 kΩ) is used in practice, giving an actual output of approximately 3.328 V — within the ±2% tolerance the downstream digital logic and CAN transceiver both accept.

## 2.3 Physical CAN Bus Interface — SN65HVD230

The SN65HVD230DR is a 3.3 V-native CAN transceiver compliant with ISO 11898-2, chosen specifically because it eliminates the level-shifting network that would otherwise be required between a 3.3 V MCU and a 5 V-logic transceiver, reducing both component count and an additional failure surface on the bus-facing side of the board.

TVS protection is provided by a NUP2105L dual-line automotive ESD/EFT suppressor placed directly across CAN_H and CAN_L, as close to the J1962 connector as routing allows, so that transient energy is diverted before it reaches the transceiver’s bus pins.

The 120 Ω termination footprint (JP1) is deliberately left open by default. Vehicle CAN buses already present the correct differential termination (typically two 120 Ω terminators at the ECU and gateway ends of the bus, combining to a nominal 60 Ω differential load); adding a third 120 Ω termination at the dongle would over-load the bus, degrading signal integrity rather than improving it. JP1 exists only to permit standalone bench testing of Board 1 against a CAN bus simulator, where no other termination is present.

## 2.4 Dual-Power Conflict Prevention

During bench calibration it is common to have Board 1 connected simultaneously to a laptop (via USB-C, for flashing/logging) and to a bench 12 V supply or live vehicle harness (for CAN traffic). Without protection, the buck converter’s 3.3 V output — or in a fault condition, the raw 12 V rail — could back-feed through the USB connector into the laptop’s USB port. A low forward-voltage Schottky diode (BAT54 or SS14) is placed in series with the USB-C 5 V VBUS net, oriented so that current can only flow from the USB host into the board, never the reverse direction, isolating the two supply domains during concurrent connection.

# 3. Board 2: Cockpit Instrument Display Node

## 3.1 Processing Core — ESP32-S3-WROOM-1-N8R8

Board 2 uses the dual-core Xtensa LX7 ESP32-S3-WROOM-1-N8R8 module, clocked at 240 MHz from the same 40 MHz-reference PLL architecture used on Board 1, with 512 kB internal SRAM augmented by 8 MB of embedded Octal PSRAM and 8 MB of Quad SPI flash. The additional core (relative to Board 1’s single-core part) and the PSRAM frame buffer are both required by the graphics workload rather than by the wireless link.

Task allocation is fixed by design: Core 0 owns the wireless protocol stack — unpacking incoming ESP-NOW telemetry frames and servicing background BLE tasks — while Core 1 is dedicated exclusively to the LVGL rendering pipeline and the DMA-driven SPI transfer to the display controller. This separation ensures that radio interrupt servicing never stalls the frame render loop, and that a full 240×240 RGB565 frame buffer (240 × 240 × 2 bytes = 115,200 bytes per frame) can be held in PSRAM without contending with the 512 kB internal SRAM budget needed for the wireless stack and LVGL object heap.

## 3.2 Display & Touch Subsystem

The panel is a Waveshare 1.28-inch circular IPS TFT (240×240, RGB565, active diameter ≈ 32.4 mm) driven by the GC9A01 controller over a 4-wire SPI interface (MOSI, SCLK, CS, DC) with DMA-assisted transfers, paired with a CST816S capacitive touch controller on a standard I2C bus.

### 3.2.1 SPI throughput and frame-rate budget

Each full-frame transfer moves the entire 115,200-byte RGB565 buffer across the SPI bus. At a 40 MHz SPI clock, the raw bit rate available for data transfer is:

Rbit = fSPI = 40 × 10⁶ bit/s ⇒ Rbyte = 5 × 10⁶ byte/s (ideal, 8 bit/clk)

The minimum time to shift out one full frame is therefore:

tframe = Bytesframe / Rbyte = 115,200 / 5,000,000 ≈ 23.0 ms

which corresponds to a theoretical ceiling of roughly 43 FPS for full-frame refresh. In practice LVGL is configured to redraw only the dirty rectangles that changed between frames (needle sweep, changing digits) rather than the full 240×240 buffer every cycle; for a typical dirty-region update covering roughly half the panel area, the transfer time roughly halves to ≈ 11.5 ms, and combined with the DMA engine offloading the transfer from the CPU (allowing LVGL to begin composing the next frame while the previous DMA transfer is still in flight), the pipeline comfortably sustains greater than 30 FPS, satisfying the design requirement.

## 3.3 USB Input Protection

The USB-C input on Board 2 is protected by a three-stage network: an 0805 surface-mount PTC resettable fuse (500 mA hold / 1 A trip) provides recoverable over-current protection ahead of the charger and system load; a SMAJ5.0A unidirectional TVS diode clamps VBUS transients above approximately 5.5 V; and a USBLC6-2SC6 low-capacitance ESD array protects the D+/D- native-USB data lines without introducing enough parasitic capacitance to distort full-speed USB signal integrity.

## 3.4 Dynamic Hardware Power-Path & Battery Subsystem

Board 2 must transition seamlessly between USB power and a single-cell 3.7 V LiPo battery (500–1000 mAh) without a software-mediated switchover, since a firmware fault or reset must never leave the display node unpowered mid-transition. This is achieved with a purely analog power-path built from a TP4056 (or MCP73831) linear charger, an AO3401A P-channel MOSFET, and a small Schottky diode network.

### 3.4.1 Switching dynamics — USB plug-in event

- VBUS rises to 5 V; the TP4056 detects input power and begins charging the LiPo cell (current limited by RPROG, configured for ≈ 400 mA).
- The same VBUS rail is applied to the gate of the AO3401A P-channel MOSFET through the gate network; because VGS becomes strongly positive relative to the battery-referenced source, the P-FET turns OFF, disconnecting the battery from the system rail.
- System load current is now supplied from VBUS through the SS14/BAT54C Schottky diode directly to the system rail, in parallel with (but electrically isolated from) the charging path into the battery.

### 3.4.2 Switching dynamics — USB unplug event

- VBUS collapses toward 0 V; the TP4056 charge path ceases sourcing current.
- The 100 kΩ pulldown resistor on the P-FET gate, no longer overridden by VBUS, pulls the gate toward the battery-referenced source potential.
- As VGS crosses the AO3401A’s threshold, the P-FET turns ON, presenting an ultra-low on-resistance path (< 30 mV drop at typical system load) directly from the battery to the system rail.
- The transition is continuous and sub-millisecond: because the P-FET body diode is oriented to conduct from battery to system rail even before the channel fully turns on, there is no interruption of supply to the ME6211C33 LDO input during the handover, and no visible flicker or reset on the display.

## 3.5 LDO Regulation — ME6211C33

The ME6211C33M5G (SOT-23-5) provides the final regulated 3.3 V system rail from either the USB-derived or battery-derived unregulated input, with a rated output current of 500 mA and a low dropout voltage of approximately 100 mV at 200 mA load. Because the LiPo discharge curve sags toward roughly 3.4 V near end-of-discharge, the LDO’s dropout margin — 3.4 V input minus 3.3 V output leaves only 100 mV of headroom at the low end of the curve — is the limiting factor that defines the battery’s usable depth of discharge before the display node begins to brown out; this is consistent with, and was a driving constraint on, the LDO part selection.

# 4. Complete Bill of Materials

The following tables consolidate every functional component referenced in §2 and §3. Passive component tolerances are 1% for feedback/sense resistors and 10% (X7R or better) for ceramic capacitors unless otherwise noted.

## 4.1 Board 1 — OBD-II Acquisition Dongle BOM

Ref | Value / Part | Package | Recommended P/N | Function
U1 | ESP32-C3-WROOM-02-N4 | SMD Module | Espressif ESP32-C3-WROOM-02-N4 | MCU / RISC-V / CAN(TWAI) / RF
U2 | TPS54302DDCR | SOT-23-6 (Thin) | TI TPS54302DDCR | 3.3V synchronous buck regulator
U3 | SN65HVD230DR | SOIC-8 | TI SN65HVD230DR | CAN 2.0B / ISO 11898-2 transceiver
D1 | SS34 | SMA / DO-214AC | Diodes Inc. SS34 | Reverse-polarity protection
D2 | SMAJ24A | SMA / DO-214AC | Littelfuse SMAJ24A | Load-dump / OV TVS clamp
D3 | NUP2105L | SOT-23 | onsemi NUP2105L | CAN_H/CAN_L ESD/EFT suppressor
D4 | BAT54 / SS14 | SOT-23 / SMA | Diodes Inc. BAT54 | USB back-feed block diode
L1 | 6.8 uH shielded inductor | 4x4 mm SMD shielded | TDK / Wurth SD-series, Isat>=2.0A | Buck output inductor
C1 | 10 uF 50V X7R | 1210 | Murata GRM32 series | Buck input bulk capacitor
C2 | 100 nF 50V X7R | 0603 | Generic MLCC | Buck input HF bypass
C3,C4 | 22 uF 10V X7R | 0805 | Murata GRM21 series | Buck output filter (x2)
R1 | 31.6 k ohm 1% | 0402 | Generic thin-film | FB divider upper (V_OUT set)
R2 | 10.0 k ohm 1% | 0402 | Generic thin-film | FB divider lower (V_OUT set)
R3 | 10 k ohm | 0402 | Generic | EN pullup
R4 | 10 k ohm | 0402 | Generic | BOOT_SEL (GPIO09) pullup
R5 | 5.1 k ohm | 0402 | Generic (x2, CC1/CC2) | USB-C CC pulldowns
JP1 | 2-pin solder jumper | SMD pad pair | Generic | 120 ohm CAN termination (default open)
R_TERM | 120 ohm 1% | 0603 | Generic | CAN termination resistor (footprint only)
J1 | J1962 OBD-II connector | Through-hole / cable mount | TE / generic OBD-II shell | Vehicle bus interface
J2 | USB-C receptacle | SMD, 16-pin | GCT / Amphenol USB4085/4110 | Flashing / bench power
SW1 | Tactile switch | SMD 6mm | Generic | Manual bootloader entry
LED1 | Status LED (red/green) | 0603 | Generic | Active-low status indicator

## 4.2 Board 2 — Cockpit Display Node BOM

Ref | Value / Part | Package | Recommended P/N | Function
U1 | ESP32-S3-WROOM-1-N8R8 | SMD Module | Espressif ESP32-S3-WROOM-1-N8R8 | Dual-core MCU / PSRAM / RF
U2 | GC9A01 display module | FPC + round glass | Waveshare 1.28" round LCD | 240x240 SPI TFT controller/panel
U3 | CST816S | COF on FPC (module) | Hynitron CST816S | Capacitive touch controller
U4 | TP4056 | SOP-8 (ESOP8) | Nanjing Top Power TP4056 | Single-cell LiPo linear charger
U5 | ME6211C33M5G | SOT-23-5 | Microne / Wuxi ME6211C33M5G | 3.3V LDO regulator
Q1 | AO3401A | SOT-23 | Alpha & Omega AO3401A | P-channel power-path MOSFET
D1 | SS14 / BAT54C | SMA / SOT-23 | Diodes Inc. SS14 | USB-to-rail power-path diode
D2 | SMAJ5.0A | SMA / DO-214AC | Littelfuse SMAJ5.0A | VBUS OV clamp
U6 | USBLC6-2SC6 | SOT-23-6 | STMicroelectronics USBLC6-2SC6 | USB D+/D- ESD array
F1 | PTC resettable fuse | 0805 | Bourns MF-USMF / Littelfuse | 500mA hold / 1A trip
BT1 | LiPo cell, 3.7V | Pouch, JST-PH connector | 500-1000 mAh generic LiPo | Battery energy storage
R1 | 100 k ohm | 0402 | Generic | P-FET gate pulldown
R2 | R_PROG (charge current set) | 0402 | Generic 1%, ~1.2k for 400mA | TP4056 charge current program
R3,R4 | 100 k ohm / 100 k ohm | 0402 | Generic 1% | Battery voltage ADC divider
J1 | USB-C receptacle | SMD, 16-pin | GCT / Amphenol USB4085/4110 | Power / flashing
J2 | JST-PH 2-pin | Through-hole SMD | JST PH series | Battery connector
SW1 | Tactile switch | SMD 6mm | Generic | Manual bootloader entry

Table 4.1/4.2 — Consolidated BOM. LCSC/DigiKey stocking numbers should be confirmed against current distributor inventory at fabrication time, as second-source equivalents (noted in §2 and §3) are acceptable substitutes for every active IC.

# 5. Manufacturing & PCB Design Guidelines

## 5.1 Stackup Specification

Layer | Function | Spec
Layer 1 (Top) | Signal + component placement | 1 oz (35 µm) copper
Core dielectric | FR-4, Tg ≥ 150°C | ≈ 1.51 mm (standard 2-layer core)
Layer 2 (Bottom) | Ground pour + secondary routing | 1 oz (35 µm) copper

Table 5.1 — 2-layer stackup used for both Board 1 and Board 2. Overall finished thickness targets the standard 1.6 mm panel spec for mechanical compatibility with generic enclosures/connectors.

Both boards are fabricated as 2-layer designs: a top signal/component layer and a bottom layer used predominantly as a continuous ground pour, broken only where necessary for short jumper traces. 1 oz copper weight is sufficient for the current levels present on both boards (peak well under 2 A on the heaviest buck output trace) while keeping fabrication cost and lead time minimal for a capstone-scale production run.

## 5.2 High-Frequency Switching Loop Routing (Buck Converter)

The TPS54302’s switch node (SW pin, inductor, and high-side/low-side FET commutation loop) is the dominant EMI source on Board 1 and must be treated as a high-di/dt loop rather than an ordinary signal net:

- Place the input bulk capacitor (C1) and HF bypass capacitor (C2) directly adjacent to the IC’s VIN and GND pins, minimizing the loop area between VIN, the capacitor, and the IC ground return — this loop, not the output inductor loop, is the primary radiator.
- Route the SW node (IC pin to inductor) as a short, wide trace with no other signals routed underneath on the opposite layer, since it carries the full switching-frequency square wave at rail voltage amplitude.
- Place the output filter capacitors (C3, C4) immediately at the inductor’s output pin, with their ground return tied directly into the same ground pour node as the IC’s power-stage ground pin — not routed around through the digital ground of the ESP32-C3.
- Keep the feedback trace (R1/R2 midpoint to FB pin) away from the SW node and inductor; route it on the quiet side of the layout and, where the trace must cross the SW net, cross perpendicular rather than parallel to minimize capacitive/inductive coupling into the feedback path.

## 5.3 Differential CAN Trace Rules

CAN_H and CAN_L are routed from the J1962 connector, through the NUP2105L ESD array, into the SN65HVD230 as a matched differential pair:

- Target differential impedance: 120 Ω (matching the ISO 11898-2 bus specification), achieved on a 2-layer FR-4 stackup with an edge-coupled microstrip geometry — trace width and spacing should be derived from a field-solver calculation against the actual fabricator’s dielectric height and copper weight rather than assumed.
- Length matching: intra-pair skew held within 50 mil (≈ 1.27 mm) end-to-end, with any necessary length compensation added as a serpentine on the shorter of the two nets immediately after the point of mismatch, not concentrated at the connector or IC end.
- Route the pair over a continuous, unbroken ground reference (no plane splits or via stitching gaps beneath the pair) for its entire length to maintain a consistent return path and avoid impedance discontinuities.
- Keep at least 3x the trace-to-trace spacing as clearance between the CAN pair and any other switching net, particularly the buck converter’s SW node and the ESP32-C3’s crystal traces.

## 5.4 Antenna RF Ground-Plane Clearance

Both the ESP32-C3-WROOM-02 and ESP32-S3-WROOM-1 modules integrate a PCB trace/chip antenna along one edge of the module footprint. On both boards:

- No copper, ground pour, silkscreen, or solder mask cutout artifacts are placed on any layer directly beneath the vendor-specified antenna keepout region — including the bottom-layer ground pour, which must be relieved under the antenna, not just the top layer.
- The module is placed at the physical edge of the PCB with the antenna pointing outward, and no metal enclosure wall, connector shell, or battery pouch (on Board 2) is placed within the module vendor’s minimum clearance distance of the antenna edge.
- Long conductive traces (including the CAN differential pair on Board 1 and the SPI display bus on Board 2) are routed away from the antenna keepout zone rather than skirting its boundary, since parallel routing close to the keepout edge can still detune the antenna even outside the strict no-copper region.

## 5.5 Board 2 — Battery and Charge Path Layout Notes

The TP4056’s thermal pad and RPROG sense resistor trace are kept short and thermally isolated from the ME6211C33 LDO’s dissipation path to avoid cross-heating that would otherwise skew the programmed charge current. The AO3401A footprint orientation is verified against the schematic’s body-diode polarity before release to fabrication: a mirrored footprint silently reverses the power-path behavior described in §3.4, producing a board that appears to power up normally on the bench (USB present) but fails immediately upon USB disconnect — a failure mode that is easy to miss without deliberately testing the unplug transition during bring-up.

— End of Hardware Engineering Chapter —

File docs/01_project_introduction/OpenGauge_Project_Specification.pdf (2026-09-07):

# DashNode: Technical Specification & System Architecture

### Undergraduate IT Engineering Capstone Project | Modular Vehicle Telemetry Platform

## 1. Executive Summary & Problem Definition

Modern vehicle instrument clusters frequently lack configurable, high-precision telemetry such as continuous intake air temperature, true oil temperature, or dynamic ECU bus parameters. Commercially available auxiliary gauges often introduce significant cabin clutter through intrusive physical wiring harnesses, while generic smartphone applications suffer from slow manual Bluetooth connectivity and severe battery drain. DashNode introduces an open-source, split-architecture automotive telemetry platform that cleanly decouples high-speed data acquisition from dashboard visualization.

The acquisition node directly interfaces with the legislated J1962 (OBD-II) port under the footwell, running an automotive-grade buck regulator and an integrated CAN transceiver. Telemetry frames are filtered, parsed, and broadcasted over a dedicated low-latency 2.4 GHz wireless link (ESP-NOW) to an auxiliary compact circular gauge node mounted in the driver's visual line-of-sight.

## 2. Hardware Subsystems & Component Specifications

The physical architecture is partitioned into two independent hardware modules to isolate automotive power transients from the user interface:

Subsystem | Component / Controller | Key Engineering Characteristics
Acquisition MCU | ESP32-C3-WROOM-02 | Single-core 32-bit RISC-V @ 160MHz, built-in TWAI (CAN 2.0B), integrated 2.4 GHz RF.
Step-Down Buck | TPS54302 / MP2315 | Input 4.5V–28V, synchronous switching @ 400kHz–500kHz, TVS & Schottky protection.
CAN Transceiver | SN65HVD230 / TJA1051T/3 | 3.3V logic compatibility, ISO 11898 compliant, optional switchable 120Ω bus load.
Display MCU | ESP32-S3-WROOM-1 | Dual-core Xtensa LX7, 8MB Octal PSRAM, dedicated Core 1 hardware graphics processing.
Display Panel | 1.28" Round IPS TFT (GC9A01) | 240x240 circular active area, 4-wire high-speed SPI with DMA support, CST816S capacitive touch.

## 3. Firmware Architecture & Protocol Stack

A. Acquisition Loop: The ESP32-C3 TWAI engine initializes at 500 kbps (standard 11-bit ISO 15765-4). A hardware timer schedules cyclic OBD-II PID query frames (Mode 01): RPM (0x0C) and Speed (0x0D) polled at 10–20 Hz, while Coolant Temp (0x05) and Ambient/Intake Temps (0x0F) are queried at 1 Hz to preserve bus bandwidth.
B. Wireless Peer-to-Peer Pipeline: Data frames are packed into a compact 16-byte binary struct and broadcasted using ESP-NOW. This connectionless protocol bypasses Wi-Fi handshake overhead, delivering telemetry packet latencies under 5 ms.
C. Dual-Core Display Execution: The ESP32-S3 allocates tasks across separate processing cores to prevent GUI stutter:

- Core 0: Wireless telemetry packet reception, checksum verification, and optional BLE media background services.
- Core 1: Light and Versatile Graphics Library (LVGL) render engine refreshing circular needle animations and digital readouts.

## 4. Implementation Milestones & Risk Control

Phase / Milestone | Duration | Key Deliverables & Verification Criteria
Phase 1: Proof-of-Concept | Weeks 1–2 | Breadboard CAN transceiver verification; ESP-NOW packet link; basic LVGL gauge render.
Phase 2: Custom Hardware | Weeks 3–4 | KiCad schematic capture; buck regulator calculation; 2-layer PCB layout; fab order release.
Phase 3: Integration | Weeks 5–6 | SMD assembly; power rail validation (12V to 3.3V); vehicle live bus testing; enclosure print.
Phase 4: Defense & Thesis | Weeks 7–8 | Thesis documentation; dynamic latency bench measurements; final university presentation.

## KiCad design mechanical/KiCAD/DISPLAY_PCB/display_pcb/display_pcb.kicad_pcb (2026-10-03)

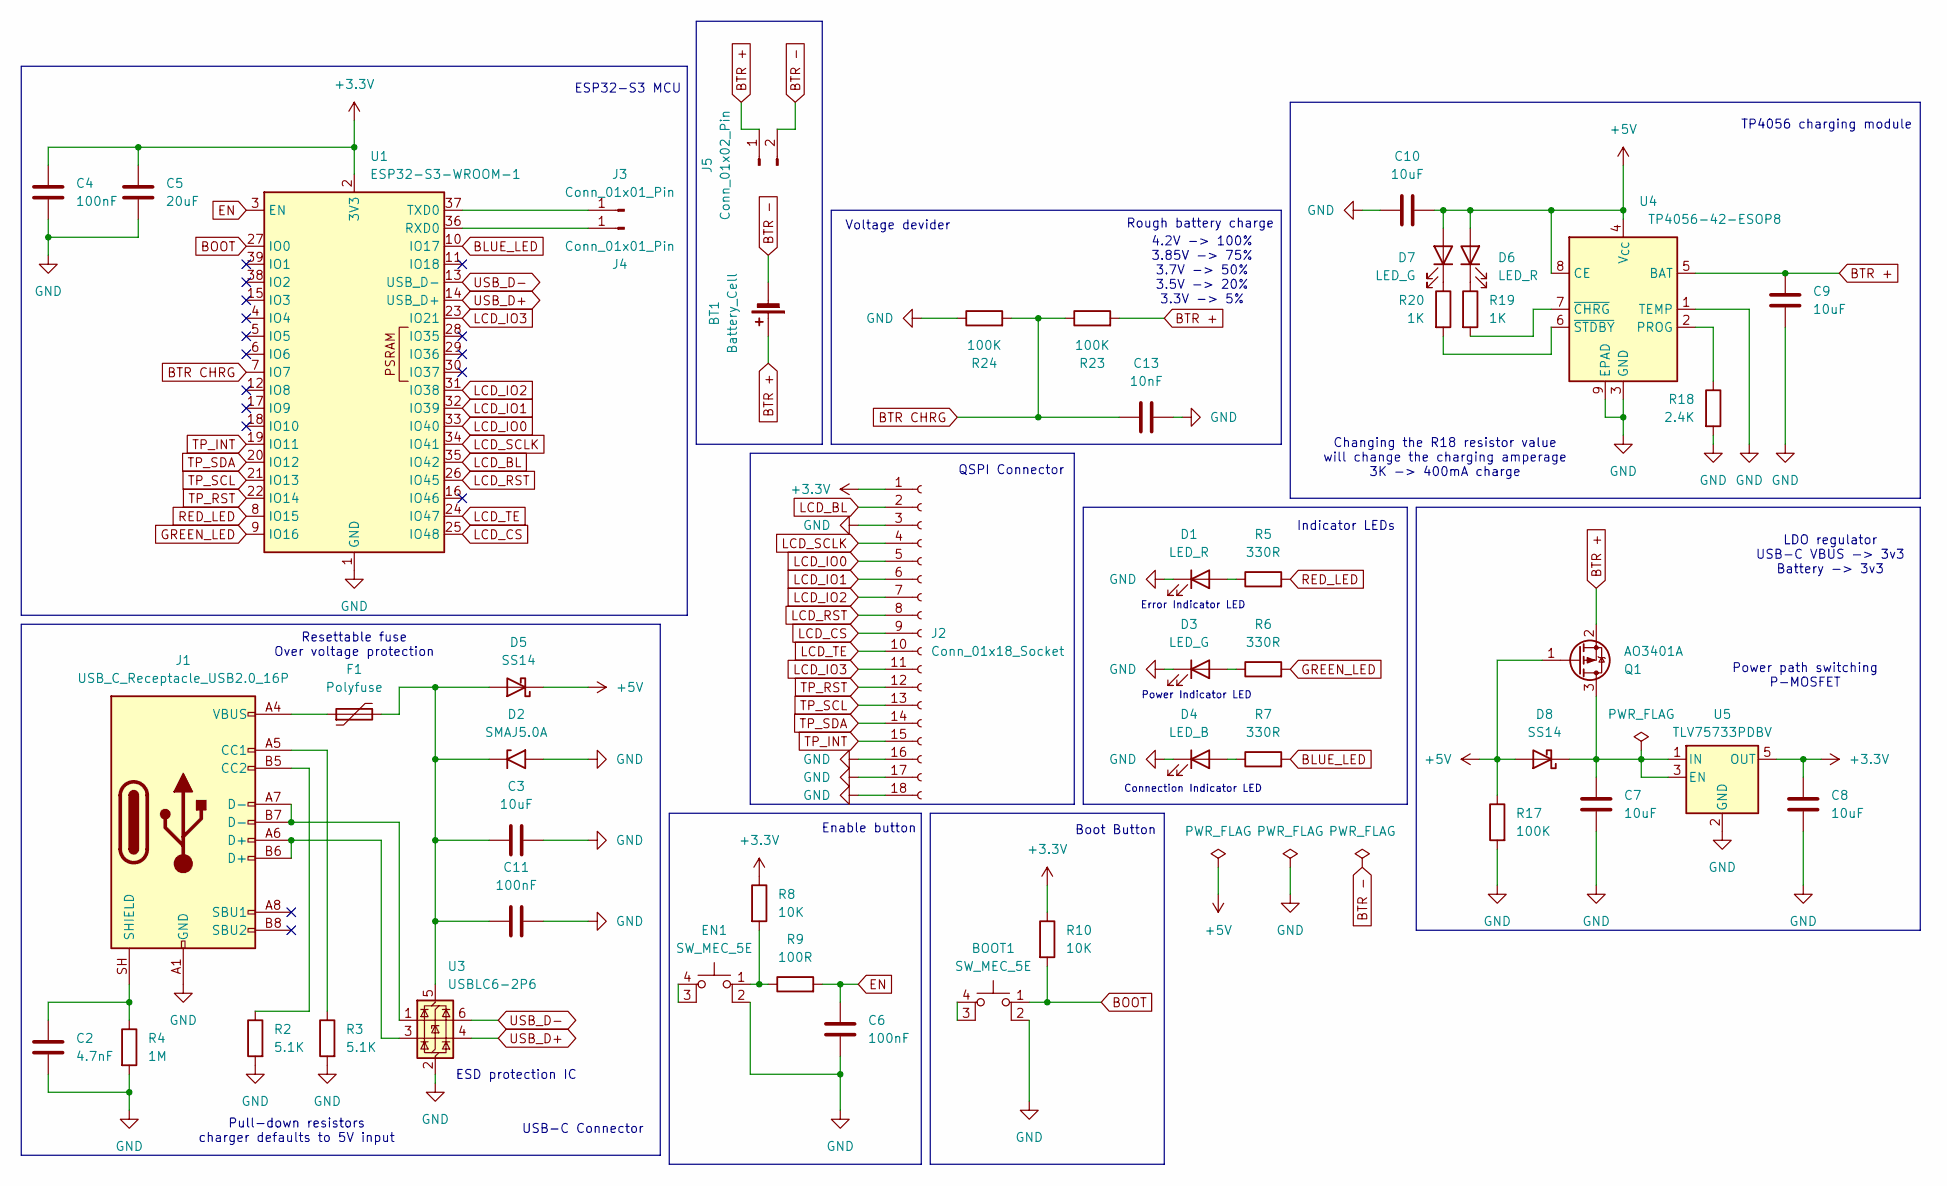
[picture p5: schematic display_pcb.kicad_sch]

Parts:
BOOT1: SW_MEC_5E; SW_SPST_EVQP2_MiddlePushTravel_H2.5mm
BT1: Battery_Cell
C2: 4.7nF; C_0805_2012Metric
C3, C7, C8, C9, C10: 10uF; C_1206_3216Metric
C4, C11: 100nF; C_0805_2012Metric
C5: 20uF; C_1206_3216Metric
C6: 100nF; C_1206_3216Metric
C13: 10nF; C_0805_2012Metric
D1, D6: LED_R; LED_0805_2012Metric_Pad1.15x1.40mm_HandSolder
D2: SMAJ5.0A; D_SMA
D3, D7: LED_G; LED_0805_2012Metric_Pad1.15x1.40mm_HandSolder
D4: LED_B; LED_0805_2012Metric_Pad1.15x1.40mm_HandSolder
D5, D8: SS14; D_SMA
EN1: SW_MEC_5E; SW_SPST_EVQP2_MiddlePushTravel_H2.5mm
F1: Polyfuse; Fuse_0805_2012Metric
J1: USB_C_Receptacle_USB2.0_16P; USB_C_Receptacle_GCT_USB4105-xx-A_16P_TopMnt_Horizontal
J2: Conn_01x18_Socket; Hirose_FH12-18S-0.5SH_1x18-1MP_P0.50mm_Horizontal
J3, J4: Conn_01x01_Pin; TestPoint_Pad_3.0x3.0mm
J5: Conn_01x02_Pin; Molex_PicoBlade_53261-0271_1x02-1MP_P1.25mm_Horizontal
Q1: AO3401A; SOT-23
R2, R3: 5.1K; R_0805_2012Metric
R4: 1M; R_1206_3216Metric
R5, R6, R7: 330R; R_0805_2012Metric
R8, R10: 10K; R_0805_2012Metric
R9: 100R; R_0805_2012Metric
R17, R23, R24: 100K; R_0805_2012Metric
R18: 2.4K; R_0805_2012Metric
R19, R20: 1K; R_0805_2012Metric
U1: ESP32-S3-WROOM-1
U3: USBLC6-2P6; SOT-666
U4: TP4056-42-ESOP8; SOIC-8-1EP_3.9x4.9mm_P1.27mm_EP2.41x3.3mm_ThermalVias
U5: TLV75733PDBV; SOT-23-5

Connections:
+3.3V: C4.1, C5.1, C8.1, J2.1, R8.1, R10.1, U1.2 (3V3), U5.5 (OUT)
+5V: C10.2, D5.1 (K), D6.2 (A), D7.2 (A), D8.2 (A), Q1.1 (G), R17.1, U4.4 (V_{CC}), U4.8 (CE)
BLUE_LED: R7.2, U1.10 (IO17)
BOOT: BOOT1.1, R10.2, U1.27 (IO0)
BTR +: BT1.1 (+), C9.1, J5.1, Q1.2 (S), R23.2, U4.5 (BAT)
BTR -: BT1.2 (-), J5.2
BTR CHRG: C13.1, R23.1, R24.2, U1.7 (IO7)
EN: C6.2, R9.2, U1.3 (EN)
GND: BOOT1.2, C2.2, C3.1, C4.2, C5.2, C6.1, C7.2, C8.2, C9.2, C10.1, C11.1, C13.2, D1.1 (K), D2.2 (A2), D3.1 (K), D4.1 (K), EN1.2, J1.A1 (GND), J1.A12 (GND), J1.B1 (GND), J1.B12 (GND), J2.3, J2.16, J2.17, J2.18, R2.2, R3.2, R4.2, R17.2, R18.2, R24.1, U1.1 (GND), U1.40 (GND), U1.41 (GND), U3.2 (GND), U4.1 (TEMP), U4.3 (GND), U4.9 (EPAD), U5.2 (GND)
GREEN_LED: R6.2, U1.9 (IO16)
LCD_BL: J2.2, U1.35 (IO42)
LCD_CS: J2.9, U1.25 (IO48)
LCD_IO0: J2.5, U1.33 (IO40)
LCD_IO1: J2.6, U1.32 (IO39)
LCD_IO2: J2.7, U1.31 (IO38)
LCD_IO3: J2.11, U1.23 (IO21)
LCD_RST: J2.8, U1.26 (IO45)
LCD_SCLK: J2.4, U1.34 (IO41)
LCD_TE: J2.10, U1.24 (IO47)
unnamed: D1.2 (A), R5.1
unnamed: C3.2, C11.2, D2.1 (A1), D5.2 (A), F1.2, U3.5 (VBUS)
unnamed: D3.2 (A), R6.1
unnamed: D4.2 (A), R7.1
unnamed: D6.1 (K), R19.1
unnamed: D7.1 (K), R20.1
unnamed: C7.1, D8.1 (K), Q1.3 (D), U5.1 (IN), U5.3 (EN)
unnamed: EN1.1, R8.2, R9.1
unnamed: F1.1, J1.A4 (VBUS), J1.A9 (VBUS), J1.B4 (VBUS), J1.B9 (VBUS)
unnamed: J1.A5 (CC1), R3.1
unnamed: J1.B5 (CC2), R2.1
unnamed: J1.A6 (D+), J1.B6 (D+), U3.3 (I/O2)
unnamed: J1.A7 (D-), J1.B7 (D-), U3.1 (I/O1)
unnamed: C2.1, J1.SH (SHIELD), R4.1
unnamed: J3.1 (Pin_1_1), U1.37 (TXD0)
unnamed: J4.1 (Pin_1_1), U1.36 (RXD0)
unnamed: R18.1, U4.2 (PROG)
unnamed: R19.2, U4.7 (~CHRG)
unnamed: R20.2, U4.6 (~STDBY)
RED_LED: R5.2, U1.8 (IO15)
TP_INT: J2.15, U1.19 (IO11)
TP_RST: J2.12, U1.22 (IO14)
TP_SCL: J2.13, U1.21 (IO13)
TP_SDA: J2.14, U1.20 (IO12)
USB_D+: U1.14 (USB_D+), U3.4 (I/O2)
USB_D-: U1.13 (USB_D-), U3.6 (I/O1)

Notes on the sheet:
Enable button
Power Indicator LED
Resettable fuse Over voltage protection
ESP32-S3 MCU
Error Indicator LED
4.2V -> 100% 3.85V -> 75% 3.7V -> 50% 3.5V -> 20% 3.3V -> 5%
Connection Indicator LED
Indicator LEDs
QSPI Connector
Rough battery charge
Changing the R18 resistor value will change the charging amperage 3K -> 400mA charge
TP4056 charging module
LDO regulator USB-C VBUS -> 3v3 Battery -> 3v3
Voltage devider
Boot Button
USB-C Connector
Power path switching P-MOSFET
Pull-down resistors charger defaults to 5V input
ESD protection IC

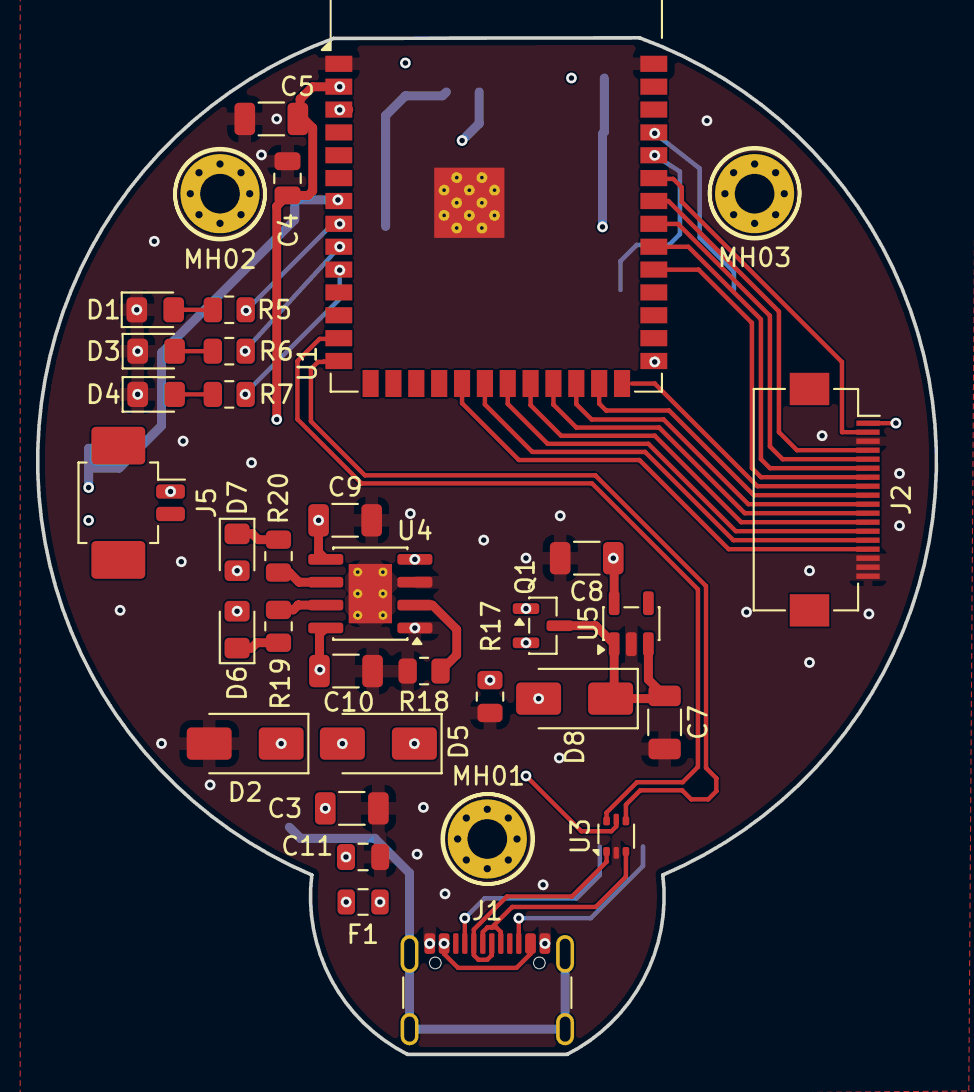
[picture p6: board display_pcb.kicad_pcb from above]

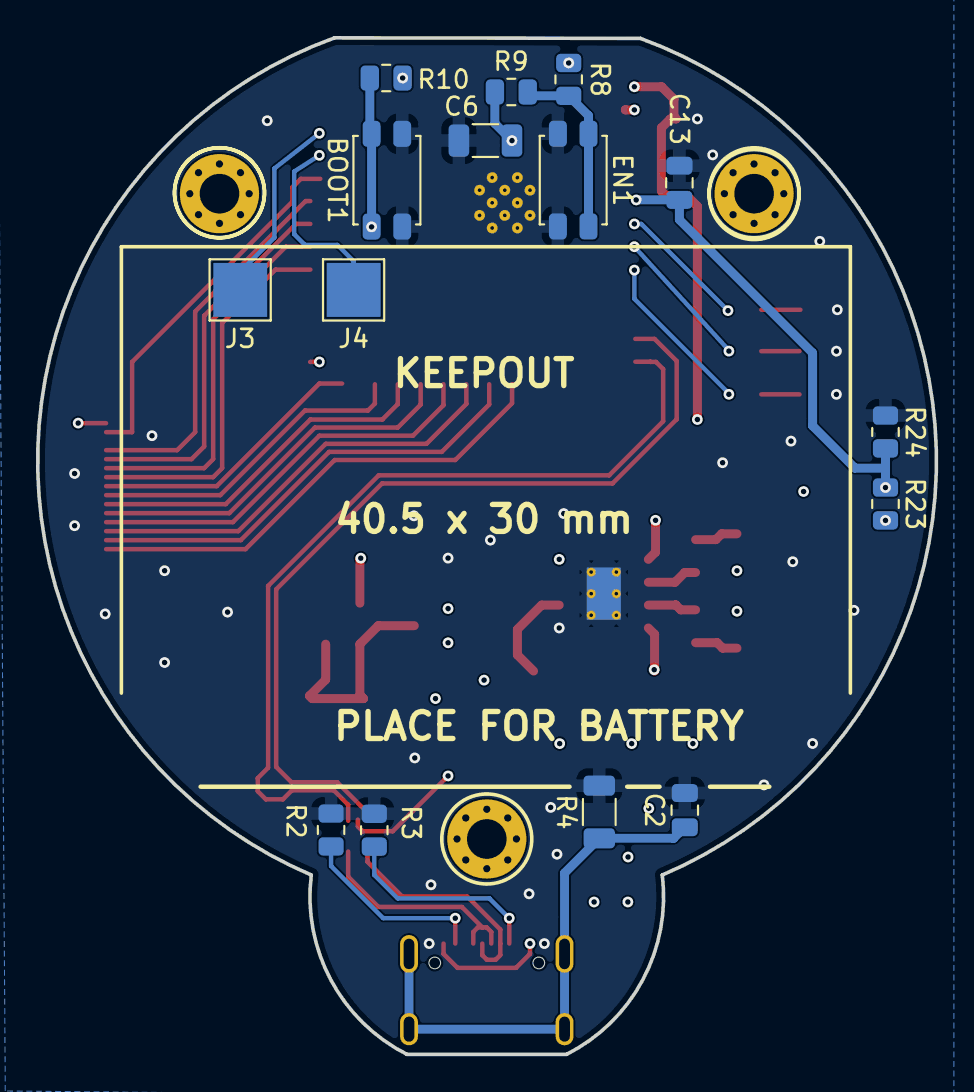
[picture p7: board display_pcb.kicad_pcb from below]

Board: 4 copper layers, 49.9 x 56.5 mm, 50 parts (15 on the bottom side), 44 nets.

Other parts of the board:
MH01, MH02, MH03: MountingHole_2.2mm_M2_Pad_Via

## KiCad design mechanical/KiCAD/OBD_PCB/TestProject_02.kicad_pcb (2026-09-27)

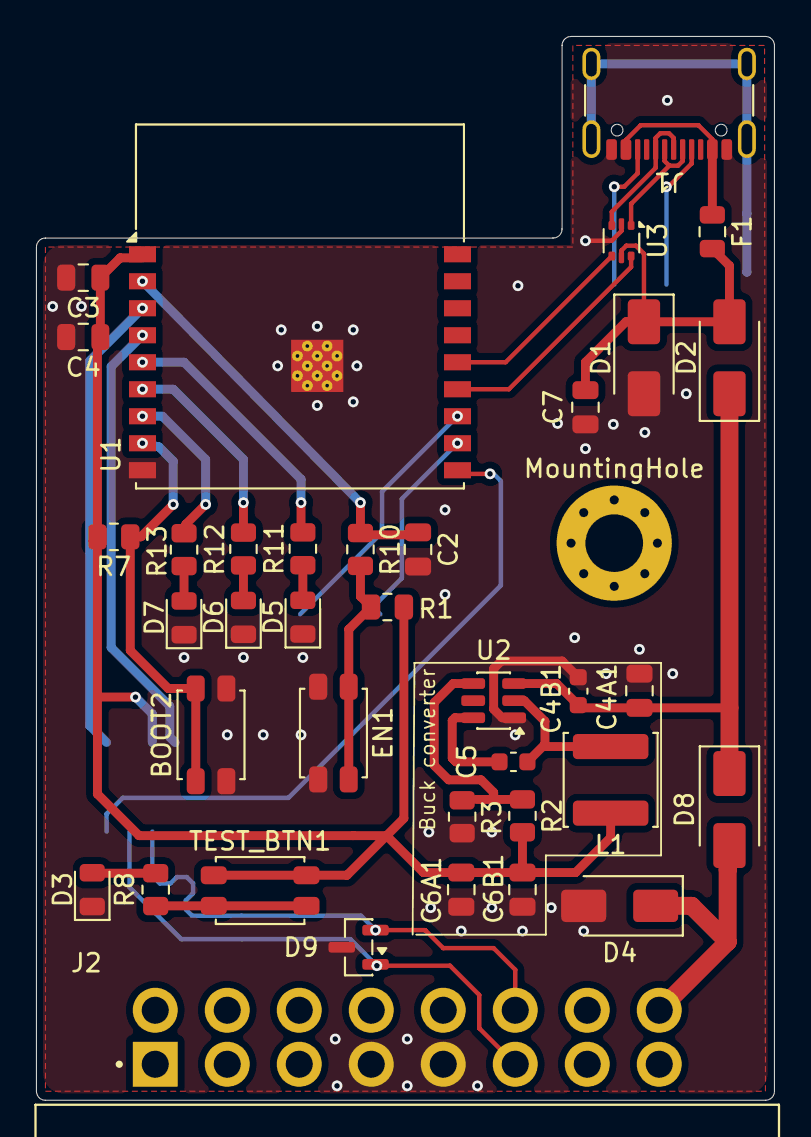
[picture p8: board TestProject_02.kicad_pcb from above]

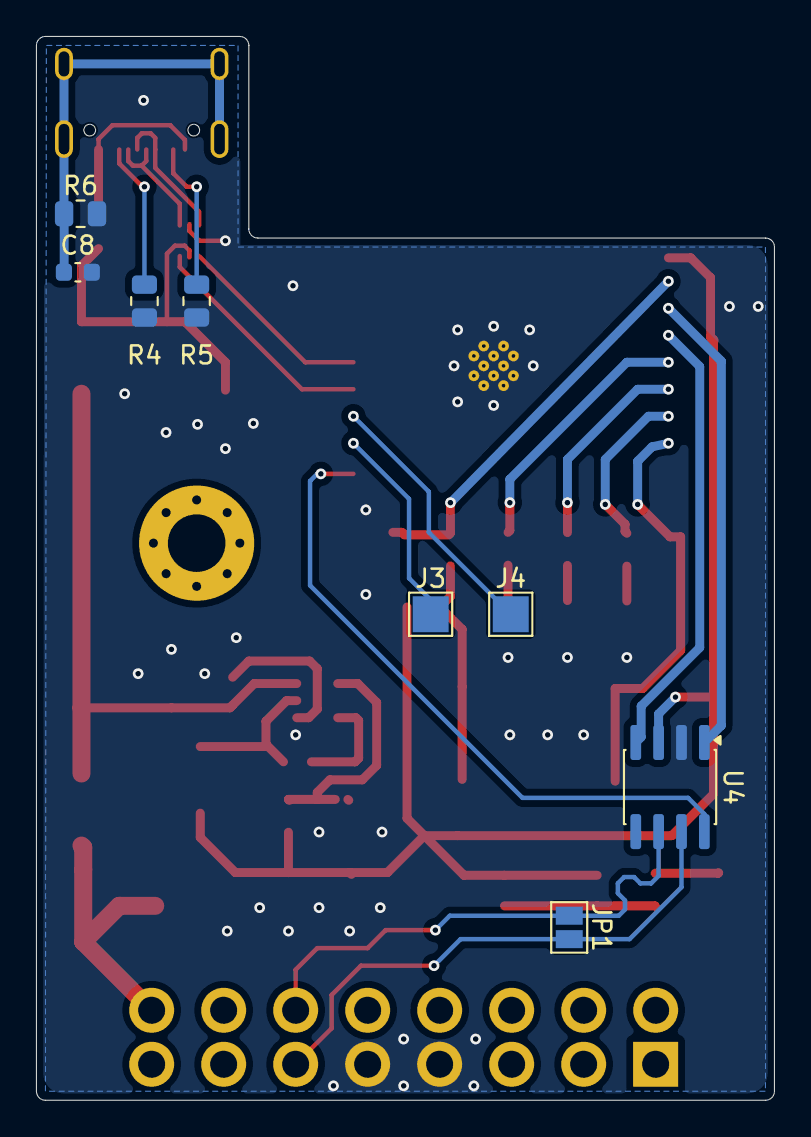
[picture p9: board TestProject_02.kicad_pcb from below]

Board: 2 copper layers, 41.0 x 59.1 mm, 46 parts (8 on the bottom side), 34 nets.

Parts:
BOOT2: SW_MEC_5E; SW_SPST_EVQP2_MiddlePushTravel_H2.5mm
C2, C3: 0.1 uF; C_0805_2012Metric
C4: 10 uF; C_0805_2012Metric
C4A1, C7: 10uF; C_0805_2012Metric
C4B1: 100nF; C_0603_1608Metric
C5: 0.1 uF; C_0603_1608Metric
C6A1, C6B1: 22uF; C_0805_2012Metric
C8: 4.7nF; C_0603_1608Metric
D1: SMAJ5.0A; D_SMA
D2: SS14; D_SMA
D3, D5: LED_G; LED_0805_2012Metric
D4: SMAJ24A; D_SMA
D6: LED_B; LED_0805_2012Metric
D7: LED_R; LED_0805_2012Metric
D8: SS34; D_SMA
D9: NUP2105L; SOT-23
EN1: SW_MEC_5E; SW_SPST_EVQP2_MiddlePushTravel_H2.5mm
F1: Polyfuse; Fuse_0805_2012Metric
J1: USB_C_Receptacle_USB2.0_16P; USB_C_Receptacle_GCT_USB4105-xx-A_16P_TopMnt_Horizontal
J2: C-OBD-II-16M; COMTECH_C-OBD-II-16M
J3: TXD_PAD; TestPoint_Pad_2.0x2.0mm
J4: RXD_PAD; TestPoint_Pad_2.0x2.0mm
JP1: SolderJumper_2_Open; SolderJumper-2_P1.3mm_Open_Pad1.0x1.5mm
L1: 10uH; L_Sunlord_SWPA5040S
MountingHole: MountingHole_3.2mm_M3_Pad_Via
R1, R3, R7: 10k; R_0805_2012Metric
R2: 45.3K; R_0805_2012Metric
R4, R5: 5.1K; R_0805_2012Metric
R6: 1M; R_0805_2012Metric
R8: 1.5K; R_0805_2012Metric
R10: 100R; R_0805_2012Metric
R11, R12, R13: 330R; R_0805_2012Metric
TEST_BTN1: SW_MEC_5E; SW_SPST_EVQP2_MiddlePushTravel_H2.5mm
U1: ESP32-C3-WROOM-02
U2: TPS54302; SOT-23-6
U3: USBLC6-2P6; SOT-666
U4: SN65HVD231; SOIC-8_3.9x4.9mm_P1.27mm

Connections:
+3.3V: C3.1, C4.1, C6A1.1, C6B1.1, L1.2, R1.2, R2.2, R7.2, TEST_BTN1.1, U1.1 (3V3), U4.3 (VCC)
/D+: J1.A6 (D+), J1.B6 (D+), U3.3 (I/O2)
/D-: J1.A7 (D-), J1.B7 (D-), U3.1 (I/O1)
BOOT: BOOT2.1, R7.1, U1.8 (IO9)
CANH: D9.1 (K), J2.6, JP1.2 (B), U4.7 (CANH)
CANL: D9.2 (K), J2.14, JP1.1 (A), U4.6 (CANL)
CAN_RX: U1.4 (IO5), U4.4 (R)
CAN_TX: U1.3 (IO4), U4.1 (D)
EN: C2.1, R10.1, U1.2 (EN)
GND: BOOT2.2, C2.2, C3.2, C4.2, C4A1.2, C4B1.2, C6A1.2, C6B1.2, C7.2, C8.1, D1.2 (A2), D3.1 (K), D4.2 (A2), D5.1 (K), D6.1 (K), D7.1 (K), D9.3 (A), EN1.2, J1.A1 (GND), J1.A12 (GND), J1.B1 (GND), J1.B12 (GND), J2.4, J2.5, R3.1, R4.2, R5.2, R6.2, U1.9 (GND), U1.19 (GND), U2.1 (GND), U3.2 (GND), U4.2 (GND)
unnamed: C7.1, D1.1 (A1), D2.2 (A), F1.2, U3.5 (VBUS)
unnamed: D3.2 (A), R8.1
unnamed: D4.1 (A1), D8.2 (A), J2.16
unnamed: D5.2 (A), R11.2
unnamed: D6.2 (A), R12.2
unnamed: D7.2 (A), R13.2
unnamed: EN1.1, R1.1, R10.2
unnamed: F1.1, J1.A4 (VBUS), J1.A9 (VBUS), J1.B4 (VBUS), J1.B9 (VBUS)
unnamed: J1.A5 (CC1), R4.1
unnamed: J1.B5 (CC2), R5.1
unnamed: C8.2, J1.SH (SHIELD), R6.1
unnamed: J3.1 (Pin_1_1), U1.11 (IO20/RXD)
unnamed: J4.1 (Pin_1_1), U1.12 (IO21/TXD)
unnamed: R8.2, TEST_BTN1.2
unnamed: R11.1, U1.5 (IO6)
unnamed: R12.1, U1.6 (IO7)
unnamed: R13.1, U1.7 (IO8)
unnamed: C5.1, U2.6 (BOOT)
unnamed: R2.1, R3.2, U2.4 (FB)
unnamed: C5.2, L1.1, U2.2 (SW)
OPMODE: U1.10 (IO10), U4.8 (Rs)
USB_D+: U1.14 (IO19), U3.4 (I/O2)
USB_D-: U1.13 (IO18), U3.6 (I/O1)
VIN: C4A1.1, C4B1.1, D2.1 (K), D8.1 (K), U2.3 (VIN)

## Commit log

2026-09-14 Moved KiCAD project to the github repo folder, changed the main readme.md so now the images can load in.
    [OBD_PCB_EN_BTN.kicad_sch, OBD_PCB_RST_BTN.kicad_sch, TestProject_02.kicad_pcb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]
2026-09-14 Editing the schematic drawing for the OBD PCB, still needs somepolishing and cleaning up.
    [TestProject_02.kicad_sch]
2026-09-15 Small changes in the schematic layout, organized the components into blocks, changed some wrong footprints
    [TestProject_02.kicad_sch]
2026-09-18 Getting close to finishing the OBD PCB. Still needs some final touch ups, also some safety and reliability check.
    [TestProject_02.kicad_pcb, TestProject_02.kicad_sch]
2026-09-19 Relocated buck converter and CAN transciever, added a mounting hole to secure the casing later.
    [TestProject_02.kicad_pcb, TestProject_02.kicad_sch]
2026-09-20 Small layout changes, relocated the OBD PCB files to it's own folder. Final checks are needed.
    [OBD_PCB_EN_BTN.kicad_sch, OBD_PCB_RST_BTN.kicad_sch, TestProject_02.kicad_pcb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]
2026-09-21 Touch ups, finalizing component placements
    [TestProject_02.kicad_pcb, TestProject_02.kicad_sch]
2026-09-22 Started the display PCB, since i use QSPI the current pinouts are not correct. Some ICs are still missing or not yet intergrated.
    [TestProject_02.kicad_pcb, TestProject_02.kicad_sch, display_pcb.kicad_pcb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]
2026-09-23 Small changes, missing battery protection IC, sorted the different related parts into groups
    [display_pcb.kicad_sch]
2026-09-27 Display schematic is finished, footprints are assigned, the basic board shape has been made, now the components has to be placed.
    [TestProject_02.kicad_pcb, display_pcb.kicad_pcb, display_pcb.kicad_sch]
2026-09-28 Related components are grouped together, they are roughly placed on the PCB. The battery protection may have to go due space limitations (most LiPO batteries has built-in protection). The PCB will be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
    [display_pcb.kicad_pcb, display_pcb.kicad_sch]
2026-09-29 The components are placed, the flex cable connector pinout has to be changed, the protection circuit was deleted because of limited space.
    [display_pcb.kicad_pcb, display_pcb.kicad_sch]
2026-09-29 Main power lines are connected, the USB ESD protection IC and the flex cable connector is not yet wired. Some components may need some more layout fixing.
    [display_pcb.kicad_pcb]
2026-09-30 Relocated some components for the high signal routes, the flex cable connector is still not in a fixed location. The buttons and the LEDs may have to be relocated for easier routing.
    [display_pcb.kicad_pcb, display_pcb.kicad_sch]
2026-10-03 Display PCB is basically finished, all routes are connected, all data lines should be within the length difference tolerance level, some spacing tolerances are still not fixed.
    [display_pcb.kicad_pcb, display_pcb.kicad_sch]
2026-10-05 OBD and displa PCB are both basically finished, some files has to be generated and the PCBs can be ordered. Documentation should be the next step.
2026-10-10 PCBs should be finished, they can be ordered. The plan was to finish the PCB design about a week ago. I already have the display and got two ESP devboard so i can start the software and test it.
2026-10-12 Small changes due to via and silkscreen overlaps, moved every via-in-pad seperately from soldering pad. PCBs have been ordered. Some problems occured with the buttons since the ones i chose had a 5th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
2026-10-12 Added a context file which describes the PCB which can be used to generate the documentation for the board.
2026-10-19 Módosítások a NYÁKon, volt egy hiba az útválasztó MOSFETtel, ezt csak a megrendelés után vettem észre és egy új NYÁK rendelést kellett indítani és lebeszélni JLCPCBvel hogy arra szereljék fel az alka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
2026-10-24 Kezdeti kód, az alap dolgok vannak lekódolva isotp, esp-idf csatlakozás, CAN interfész, ECU pid táblázat a lekéréshez, animáció simítás a kijelző oldalon. Ezeket tesztelni kell és utána lehet tovább 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
2026-10-24 host_test: MSVC-támogatás és figyelmeztetések javítása
    - CMakeLists.txt: MSVC alatt /W4 /utf-8, egyébként a korábbi
    -Wall -Wextra -Wpedantic (az MSVC a /Wextra kapcsolón leállt).
    - test_obd.cpp: a PID-listák std::initializer_list<uint8_t>-ként,
    így nincs int -> uint8_t szűkítés (C4244).
    - test_pid.cpp: a 'back' változó kezdőértéket kap (C4701).
    Mind az 5 PC-s teszt átmegy MSVC 19.43-mal, figyelmeztetés nélkül.
2026-10-24 TwaiBus és az S2–C3 CAN-teszt (ECU-szimulátor + OBD-kliens)
    - og_twai: TwaiBus, az ICanPort megvalósítása a TWAI-driverre (driver/twai.h).
    A send() megvárja a nyugtázást, nyugta nélkül megszakítja az adást;
    minden keret naplózható (OG_TWAI_LOG_FRAMES).
    - ecu_sim (ESP32-S2): az EcuModel valódi CAN-buszon, időzített válaszokkal
    és változó járműállapottal; menuconfigban sebesség, 29 bit, OBDonUDS,
    válaszidő, hibakódszám. Konzol: USB CDC.
    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
2026-10-24 Kijelző élesztése (M2): ST77916 QSPI-meghajtó és színteszt
    - disp_lcd: LcdPanel az esp_lcd + esp_lcd_st77916 (2.0.2) komponensre;
    QSPI-busz, DMA-képes 40 soros sávpuffer, háttérvilágítás LEDC-PWM-mel.
    - A Waveshare 1,85" panel saját ST77916 init-táblája
    (ESP32_Display_Panel, Espressif, Apache-2.0; 184 sor, változatlan
    értékekkel). A komponens alapértelmezett táblájával a kép fakó,
    csíkos és hamis színű volt; menuconfigban választható.
    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
2026-10-24 Első LVGL-teszt (M3): ív, felirat, animáció, FPS-mérés
    - lvgl_test: LVGL 9.6 az esp_lvgl_port 2.9-cel a meglévő ST77916
    panelre; részleges frissítés két 360x40-es DMA-pufferrel a belső
    RAM-ban, LVGL-feladat az 1. magon. 270°-os ív és nagy számkijelzés
    800-7000 között oda-vissza animálva; másodpercenkénti FPS- és
    memórianapló (LV_EVENT_RENDER_READY), képernyőn sysmon.
    - A színteszt külön fájlba (color_test); menuconfigban választható,
    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
2026-10-25 ESP-NOW-kapcsolat (M4) és műszerfal a valós telemetriával
    - og_espnow: EspNowLink (Wi-Fi STA, rögzített csatorna, energiatakarékosság
    nélkül; a vételi visszahívás csak sorba másol). Társcím menuconfigból,
    alapértéke a szórási cím (nincs MAC-szintű nyugta).
    - og_obd: build_telemetry (PidScheduler -> TelemetryMsg, a mező csak a
    periódusa kétszeresén belül érvényes); PidScheduler::period().
    - og_protocol: LinkStats (vett / elveszett / elavult, adó-újraindulás
    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
2026-10-26 Érintő (CST816S): meghajtó, érintésteszt, húzásos váltás; ESP-NOW tartósmérés
    - disp_lcd: TouchPanel (új i2c_master driver, belső felhúzók, reset és
    I2C-buszkeresés induláskor, esp_lcd_touch_cst816s, az automatikus alvás
    tiltása); tengelycsere/tükrözés menuconfigból.
    - display_node:
    - érintésteszt mód: pont és koordináták az érintés helyén, négy célpont
    a széleken (tájolás ellenőrzése), gesztusok a naplóban;
    - műszerfal: balra/jobbra húzás vált képernyőt, érintés után 15 s-ig
    nincs automatikus váltás;
    - board_pins.h: TouchPins mindkét hardverváltozathoz.
    Hardveren még nem tesztelve.
    - firmware/tools/serial_logger.ps1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
2026-10-26 Érintő: javított indítás és reset-kiosztás, érintésteszt-grafika; napló
    - touch_panel: saját reset után azonnal az automatikus alvás tiltása
    (a CST816T a reset után ~200-500 ms-mal elalszik), a meghajtó reset
    nélkül indul; chip-azonosító naplózása (0xB5); időzített lekérdezés
    az alapértelmezés (megszakításos mód: OG_TOUCH_USE_INT).
    - board_pins (devkit): a modul 15 pólusú csatlakozóján a két reset
    funkciója fel van cserélve a feliratához képest; kijelző RST = IO40,
    érintő RST = IO39. A Rev. A NYÁK-on ellenőrizendő (Q-36).
    - Az érintő a kijelző előtt indul; a napló jelzi, hogy utána is ébren van.
    - Érintésteszt: pont és nyom az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

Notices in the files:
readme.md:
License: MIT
